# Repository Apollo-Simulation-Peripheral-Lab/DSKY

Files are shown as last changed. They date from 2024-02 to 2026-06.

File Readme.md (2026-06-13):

# DSKY Replica
> This project is still a work-in-progress 

This projects aims to create an affordable and easy to manufacture, yet as realistic as possible replica of the DSKY used in the Apollo program to interface with the Apollo Guidance Computer (AGC).

## Quick start

**Do you want a DSKY but can't build one? Buy one [here](https://shop.ortizma.com)**

**Need Help? Join our Discord [here](https://discord.gg/CHZaYj5UNu)**

**Do you just want to have a DSKY display in your web browser?**
  - Make sure you have NodeJS > 18
  - Run start.bat and answer the prompts

**Do you want to build the whole DSKY replica?**
  - Print the .3mf/.stl meshes found in the '3D Models' folder.
    - The recommended display is the **960x544 AMOLED MIPI display**, connected to the Orange Pi via HDMI through an adapter board.
    - A legacy 40-Pin 5" 800x480 LCD variant also exists but is no longer recommended; new builds should use the AMOLED.
  - Order the PCB:
    - The board is designed to be ordered fully assembled from JLCPCB. The fabrication files (gerbers, BOM, pick-and-place positions) are in the ``Boards/Single_board/production`` folder.
  - Calibrate and flash the firmware:
    - Install PlatformIO into VSCode
    - Open this repository's root folder in VSCode — PlatformIO will pick up ``platformio.ini`` at the root
    - Each ATmega328P has a slightly different internal oscillator. You must first determine your chip's optimal OSCCAL value:
      1. Flash the ``bare_calibration`` environment to run the OSCCAL sweep
      2. Use ``firmware/tools/osccal_reader.py`` to read the sweep results and find the best value
      3. Set the ``-DOSC_CAL=0xNN`` flag in ``platformio.ini`` with your value
      4. Flash the ``bare`` environment with your calibrated firmware
  - Set up the Orange Pi:
    - See the [Orange Pi setup guide](Documentation/orangepi-setup.md).
    - Pre-built .img files have been shared around the community, but they are not recommended as they may be out of date.
  - Make sure you have NodeJS > 18
  - Run start.bat on your PC to launch the web display

**Already have a DSKY and want the latest software?**
  - Updates are installed from the DSKY itself: open the menu (press NOUN three times) and go to **SETTINGS → UPDATE**. See [Documentation/updates.md](Documentation/updates.md).

## Repository contents:
* **Documentation**: Useful information to better understand how the different pieces of the puzzle talk to each other. Includes the [Orange Pi setup guide](Documentation/orangepi-setup.md), the [OTA update system](Documentation/updates.md), how to [deploy code to a device over the network](Documentation/deploying-to-a-device.md), and how to [develop on a physical DSKY with hot reload](Documentation/dev-mode.md).
* **2D Models**: SVG files for alarm labels and backlights.
* **3D Models**:
  * **0.4 Nozzle:** All printable meshes (enclosure, display housing, keyboard plate, mounts, etc.) designed for a standard 0.4mm nozzle.
  * **Keys (0.2 Nozzle + AMS).3mf:** Multi-color key models for a 0.2mm nozzle with AMS.
* **Firmware:** PlatformIO project containing the firmware for the bare ATmega328P on the PCB. Includes OSCCAL calibration tooling.
* **Programs:**
  * **next-dsky**: Full-stack Next.js application that serves as the main DSKY UI and backend. Handles serial communication with the PCB, WebSocket connections to AGC simulators, display rendering, and configuration.    * Requirements: NodeJS >18
    * Running: ``npm install`` then ``npm start`` (or use ``start.bat`` from the repo root)
  * **DSKY-Bridge**: Submodule ([nhadrian/DSKY-Bridge](https://github.com/nhadrian/DSKY-Bridge)) — bridge utility for the DSKY.
  * **nassp-cloud**: Node.js service that monitors NASSP (orbiter simulator) telemetry via WebSocket and manages automatic restarts.
  * **click-generator**: Python program that procedurally generates relay clicking audio sequences to emulate the DSKY's relay boxes.
* **Boards**
  * **Single_board**: Unified KiCad PCB project containing the keyboard matrix, alarm lights, serial interface, and backlight driver. The ``production`` folder contains ready-to-order JLCPCB fabrication files.

## License

This project is licensed under [Creative Commons Attribution-NonCommercial-ShareAlike 4.0 International (CC BY-NC-SA 4.0)](LICENSE).

You are free to build one for yourself, modify the design, and share your changes — as long as you **credit the original**, **do not use it commercially**, and **release your derivatives under the same license**. Commercial sale of this device or its derivatives is not permitted without prior written consent from the copyright holder.

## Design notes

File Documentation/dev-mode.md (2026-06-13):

# Developing on a physical DSKY (dev mode)

This guide is for iterating on the `next-dsky` software **on a real DSKY** with a
fast edit → see-it loop: edits hot-reload on the device in seconds, with no
build and no reboot. It complements:

- [deploying-to-a-device.md](deploying-to-a-device.md) — pushing a built copy to a device (slow; for a one-off install or OTA bootstrap).
- [updates.md](updates.md) — the production OTA update system.

Use **dev mode** while actively developing. Use the other two for releasing.

> The DSKY's keyboard and indicator lamps are wired to the Orange Pi over serial,
> and the display is a Chromium kiosk on the Pi pointing at `localhost:3000`. So
> the server has to run **on the Pi**. Dev mode just runs it in Next's dev (hot
> reload) mode instead of the production build, and you sync your code to it.

## How it works (the safety model)

Dev mode is a purely **in-memory takeover** — it never changes what the device
boots:

- It does **not** touch `~/dsky-releases/current` (the OTA boot pointer). The
  configured production release stays the boot target.
- It **pauses** the production launcher (`orangepi.sh`) with `SIGSTOP` — rather
  than killing it, which would end the X session and drop the screen to the
  lightdm login prompt — and runs `npm run dev` in its place.
- A **reboot returns to production automatically**: nothing persistent changed.
  Pressing `Ctrl-C` also resumes production (the launcher is sent `SIGCONT`).

So you can power-cycle the device at any point and it boots back to normal.

## One-time setup

From your PC:

```bash
# Passwordless SSH (so syncing doesn't prompt on every save)
ssh-copy-id orangepi@<DSKY-IP>

# File-watch tool for live sync
sudo apt install -y inotify-tools

# Copy the dev launcher to the Pi (dev-sync.sh only syncs next-dsky, not the root)
scp dev.sh orangepi@<DSKY-IP>:~/DSKY/dev.sh
```

Finding `<DSKY-IP>` and SSH basics are covered in [deploying-to-a-device.md](deploying-to-a-device.md#step-2--find-the-dsky-and-connect-via-ssh).

## Entering dev mode

In one terminal, start the dev server on the Pi (keep this terminal open — it
shows the live logs):

```bash
ssh -t orangepi@<DSKY-IP> '~/DSKY/dev.sh'
```

- The **first compile is slow** (~90 s on an Orange Pi Zero 2W — it's RAM-tight
  and leans on swap). The splash stays up meanwhile; let it finish.
- When `:3000` responds, the kiosk reloads and you'll see the app in dev mode.

To **edit live**, in a second terminal on your PC:

```bash
./dev-sync.sh <DSKY-IP>        # rsyncs Programs/next-dsky on every save
```

Now edit in your local repo; changes sync to the Pi and hot-reload on the device.

## Leaving dev mode

Press `Ctrl-C` in the `dev.sh` terminal — production resumes on its own (~15 s) —
or `ssh orangepi@<DSKY-IP> 'sudo reboot'`.

## Things to know

- **No UPDATE in SETTINGS while in dev.** OTA is intentionally disabled in dev
  (it keys off `DSKY_RELEASES_DIR`, which only the production launcher sets), so
  the **UPDATE** menu entry is hidden. Return to production to install OTA updates.
- **Server-side edits cause a brief outage.** Editing a server `.ts` file restarts
  the dev server (`tsx watch`), so `:3000` is down for a few seconds. If Chromium
  reloads in that window it shows **"This site can't be reached"** and won't retry.
  The server is fine — just reload the kiosk (see below). Client `.tsx` edits use
  Next HMR and don't cause this.
- **Reloading the kiosk** (no keyboard on the DSKY) from your PC:
  ```bash
  ssh orangepi@<DSKY-IP> 'export DISPLAY=:0; killall chromium-browser chromium; \
    sleep 1; setsid chromium-browser --start-fullscreen --incognito --noerrdialogs \
    --disable-infobars --disable-session-crashed-bubble --no-default-browser-check \
    --no-first-run "http://localhost:3000/?view=screen" >/dev/null 2>&1 < /dev/null &'
  ```

## Troubleshooting

| Symptom | Cause | Fix |
|---|---|---|
| Screen stuck on a login/password prompt | An older `dev.sh` killed `orangepi.sh`, ending the X session (lightdm greeter) | Update `dev.sh` (it now `SIGSTOP`s instead); `sudo reboot` to recover |
| "This site can't be reached" on the DSKY | `:3000` was briefly down during a server restart | Reload the kiosk (command above); the server recovers on its own |
| No **UPDATE** entry in SETTINGS | You're in dev mode (OTA disabled) | Return to production (`Ctrl-C` / reboot) |
| First load takes ~90 s | Zero 2W compiling in dev under tight RAM | Normal — wait; subsequent HMR edits are fast |
| Every save prompts for a password | SSH key not installed | `ssh-copy-id orangepi@<DSKY-IP>` |

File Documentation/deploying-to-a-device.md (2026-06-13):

# Deploying code to a DSKY over the network

This guide explains how to push the `next-dsky` software onto a physical DSKY (the Orange Pi inside it) from your PC, step by step. You need this in two situations:

1. **One-time OTA bootstrap** — installing the over-the-air update system onto a device that doesn't have it yet. After this, the device updates itself from its own menu (see [updates.md](updates.md)) and you never need this guide again for that device.
2. **Developer workflow** — pushing your latest local changes to a test device to try them on real hardware, without cutting a release.

The whole process is done **from your PC's terminal**. You never plug a keyboard into the DSKY. The Orange Pi inside it is a small Linux computer on your network, and you control it remotely over SSH.

> **A note on terminology:** "from your PC" means a terminal on your normal computer. `ssh user@host '<command>'` runs `<command>` *on the Pi*, but you type it from your PC — SSH carries the command across the network for you. You do not need to "log into" the Pi manually for the deploy.

---

## Prerequisites

- The DSKY and your PC are on the **same WiFi/LAN**.
- **NodeJS > 18** on your PC (only needed if you want to test locally first).
- A clone of this repository on your PC with the code you want to deploy:
  ```bash
  git clone https://github.com/Apollo-Replica/DSKY.git
  # or, if you already have it, get the latest:
  cd DSKY && git pull
  ```
  Throughout this guide the clone is referred to as `~/DSKY` — adjust to wherever yours lives.

---

## Step 1 — Get the DSKY onto your WiFi

Skip this if the device is already on your network (e.g. via Ethernet).

### The on-device WiFi portal

In the DSKY menu (press **NOUN** three times) go to **SETTINGS → WIFI**. The device starts a temporary WiFi access point called **"DSKY Replica"** and shows a QR code.

That QR is a *"join this WiFi network"* code, **not** a scan-to-open-a-website code. If this doesn't work, connect it like this:

1. On your phone, open **Settings → WiFi** (the normal network list).
2. Connect to the network named **"DSKY Replica"**.
3. A page opens automatically (like a hotel WiFi portal) where you pick **your home WiFi** and enter its password.
4. The DSKY connects to your WiFi and the "DSKY Replica" network disappears.

---

## Step 2 — Find the DSKY and connect via SSH

### Try the hostname first

The setup guide sets the Pi's hostname to `dsky`, so this may just work:

```bash
ssh orangepi@dsky.local
```

### If that fails: find the IP address

`.local` names rely on mDNS, which **often does not work from WSL** (Linux inside Windows). If you see `Could not resolve hostname dsky.local`, don't fight it — find the device's numeric IP instead:

- **From your router:** open its admin page (usually `http://192.168.1.1`), find the connected-devices / DHCP list, and look for a device named `dsky` or `orangepi`. Note its IP (e.g. `192.168.68.104`).
- **From Windows PowerShell** (not WSL — Windows *can* resolve `.local`):
  ```powershell
  ping dsky.local
  ```
  The reply shows the IP in brackets.

> Your LAN may not use the `192.168.1.x` range. In testing it was `192.168.68.x` — always use whatever your router actually reports.

### Confirm it's the DSKY

Open the IP in your PC's browser with port `3000`:

```
http://<DSKY-IP>:3000
```

If you see the DSKY screen, the IP is correct and the device is reachable. (`Connection timed out` when you try to SSH usually means a **wrong IP**, not a DSKY problem — re-check the IP. `Connection refused` would instead mean SSH isn't running.)

### Connect

```bash
ssh orangepi@<DSKY-IP>
```

- Default password: **`orangepi`** (unless you changed it).
- **The password is invisible as you type** — no dots, no asterisks. This is normal; type it and press Enter.
- A successful login shows a prompt like `orangepi@dsky:~$`. You're now "inside" the Pi. Type `exit` to return to your PC — the deploy below doesn't need you to stay logged in.

---

## Step 3 — Deploy the code

Run these from your PC. Replace `<DSKY-IP>` with the address from Step 2, and `~/DSKY` with your local clone path. You'll be asked for the password (`orangepi`) on each command.

```bash
# 1. Copy the app code to the Pi (skip the big build/dependency folders)
rsync -av --exclude node_modules --exclude .next \
  ~/DSKY/Programs/next-dsky/ orangepi@<DSKY-IP>:~/DSKY/Programs/next-dsky/

# 2. Copy the launcher script
rsync -av ~/DSKY/orangepi.sh orangepi@<DSKY-IP>:~/DSKY/orangepi.sh

# 3. Rebuild on the Pi and reboot
ssh orangepi@<DSKY-IP> 'cd ~/DSKY/Programs/next-dsky && npm install && npm run build && sudo reboot'
```

What to expect:

- **Step 3 is slow** — several minutes. `npm install` and `npm run build` are heavy for the small Orange Pi (the build alone can take ~300s). This is normal; let it finish.
- A successful build prints `✓ Compiled successfully` followed by a small routes table.
- The command ends with **`Connection to <IP> closed by remote host`**. This is **not an error** — it's the `sudo reboot` taking effect and dropping the SSH session, exactly as intended.
- npm warnings about `vulnerabilities` or a `New major version of npm` are harmless noise — ignore them.

> **Why copy from the PC and not `git pull` on the Pi?** Either works, but copying with `rsync` deploys exactly the code on your PC — including local changes you haven't pushed yet — which is what you want for a developer test. For a clean release-based install, `git pull` on the Pi is fine too. The `rsync` excludes (`node_modules`, `.next`) keep the transfer small; Step 3 regenerates them.

---

## Step 4 — Verify

The Pi takes 4-5 minutes to boot back up. Then, on the DSKY:

1. Press **NOUN** three times → **SETTINGS**.
2. A new **UPDATE** entry should appear. (It only shows when over-the-air updates are enabled, which the new `orangepi.sh` does automatically by setting `DSKY_RELEASES_DIR`.)
3. Open **ABOUT** → it now shows a **Version** line.

If you see **UPDATE** in SETTINGS, the deploy succeeded and the device is ready for over-the-air updates from here on.

---

## After this: updates are automatic

Once a device has been bootstrapped with the steps above, you never need to do it again for that device. New versions are published as GitHub releases and installed from the DSKY's own menu (**SETTINGS → UPDATE**), with automatic rollback if anything goes wrong. See [updates.md](updates.md) for how to publish a release and how the safety/rollback mechanism works.

---

## Troubleshooting

| Symptom | Cause | Fix |
|---|---|---|
| `Could not resolve hostname dsky.local` | mDNS not working (common in WSL) | Use the numeric IP — find it via the router or `ping dsky.local` from Windows PowerShell |
| `ssh: connect to host … port 22: Connection timed out` | Wrong IP, or the device isn't reachable at that address | Confirm the IP with `http://<IP>:3000` in a browser; re-check the router's device list |
| `Connection refused` (instead of timeout) | Reachable, but SSH server not running on the Pi | Enable/start `sshd` on the Pi (needs a monitor+keyboard, or a pre-configured image) |
| Password prompt shows nothing as you type | Normal SSH behaviour | Type it blind and press Enter (default: `orangepi`) |
| QR code does nothing when scanned | It's a WiFi-join QR, not a website QR | Connect to the "DSKY Replica" network manually from your phone's WiFi settings |
| "DSKY Replica" network never appears | `wifi-connect` not installed/running on the Pi | Install it (see [orangepi-setup.md](orangepi-setup.md)) or use Ethernet |
| `Connection closed by remote host` at end of Step 3 | The `sudo reboot` dropped the session | Expected — not an error |
| Build seems stuck for a minute or two | The Orange Pi is slow to compile | Wait; ~100s for the build is normal |
| UPDATE doesn't appear in SETTINGS after reboot | `orangepi.sh` not updated, so `DSKY_RELEASES_DIR` isn't set | Make sure Step 3.2 (copying `orangepi.sh`) ran, then reboot |

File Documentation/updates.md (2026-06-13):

# Over-the-air updates

DSKYs update themselves from the device UI — owners never need a terminal. This document explains how the pieces fit together, how to publish an update, and how recovery works.

## For DSKY owners

1. Open the menu (press **NOUN** three times), go to **SETTINGS**.
2. The **UPDATE** entry shows a `NEW vX.Y.Z` badge when an update is available (the device checks automatically every few hours).
3. Select **UPDATE → INSTALL vX.Y.Z**. The display shows download progress, installs, and the DSKY restarts itself. That's it.

If anything goes wrong (power loss, WiFi drop, a bad release), the DSKY keeps or restores the previous version automatically. Updating is always safe.

## How it works

```
GitHub release (vX.Y.Z)                     Orange Pi
┌──────────────────────────┐      ┌─────────────────────────────────┐
│ next-dsky-vX.Y.Z-        │      │ ~/dsky-releases/                │
│   linux-arm64.tar.gz     │ ───▶ │   current  ──▶ vX.Y.Z/          │  ◀─ active (symlink)
│   (prebuilt, + .sha256)  │      │   vX.Y.Z/                       │
└──────────────────────────┘      │   vW.V.U/                       │  ◀─ rollback target
   built by GitHub Actions        │   previous (path of last good)  │
                                  │ ~/DSKY/Programs/next-dsky       │  ◀─ factory install (git clone,
                                  └─────────────────────────────────┘     never touched)
```

- **Releases are prebuilt by CI** ([release.yml](../.github/workflows/release.yml)) on an arm64 runner: `npm ci`, `next build`, dev dependencies pruned, everything tarballed with a SHA-256 checksum. The Orange Pi never runs `npm install` or `next build` — too slow and too fragile on a Zero 2W.
- **The updater lives in the server** ([updater.ts](../Programs/next-dsky/src/server/updater.ts)). It checks `https://api.github.com/repos/<repo>/releases/latest` every 6 hours and on entering the UPDATE screen. Installing means: download → verify checksum → unpack into a *new* directory → carry over device config (`.env`, `ha_entities.json`) → atomically switch the `current` symlink → restart.
- **The launcher is the safety net** ([orangepi.sh](../orangepi.sh)). It always starts the app from `current` (falling back to the factory install if the symlink is missing or broken). A fresh release carries a `.pending-verify` flag; the launcher counts boot attempts while that flag exists, and after 3 failed starts it points `current` back at the previous release. The server removes the flag only after running healthily for 90 seconds.

Failure cases and what happens:

| Failure | Result |
|---|---|
| Network drops mid-download | Install aborts, error shown, current version untouched |
| Corrupted download | Checksum mismatch, install aborts |
| Power loss during install | Symlink not yet switched — old version boots |
| Power loss right after install | New release boots; if broken, crash-loop rollback kicks in |
| New release crash-loops | After 3 attempts the launcher rolls back to the previous release |
| Everything in `~/dsky-releases` is broken | Launcher falls back to the factory git clone |

## Publishing an update (maintainers)

```bash
git tag v0.2.0
git push origin v0.2.0
```

The workflow builds and attaches the package to the release automatically. Devices pick it up on their next periodic check (≤6h) or when the owner opens SETTINGS → UPDATE.

Notes:
- The version shown on devices comes from the tag (CI stamps it into `package.json`); you don't need to bump `package.json` manually.
- Only the **latest** release is offered, so devices that skipped versions jump straight to the newest one. Releases must therefore always be self-contained (no incremental migrations between versions).
- Test on your own DSKY before tagging: the public release goes to every device in the field.

## Environment variables

| Variable | Default | Purpose |
|---|---|---|
| `DSKY_RELEASES_DIR` | `~/dsky-releases` (set by `orangepi.sh`) | Enables OTA and sets the install location. Unset (e.g. desktop installs) = no OTA UI. |
| `DSKY_UPDATE_REPO` | `Apollo-Replica/DSKY` | GitHub repo whose releases are checked. |

## Devices shipped before OTA existed

Older devices don't have the updater yet, so they need one manual deploy over the network to bootstrap it. The full step-by-step (finding the device, SSH, copying the code, rebuilding, and the gotchas around `.local`/WSL) is in **[deploying-to-a-device.md](deploying-to-a-device.md)**. In short:

```bash
ssh orangepi@<DSKY-IP>
cd ~/DSKY && git pull
cd Programs/next-dsky && npm install && npm run build
sudo reboot
```

From then on, all updates are OTA. New SD card images include the updater out of the box.

## Manual recovery

Should a device ever need hands-on recovery (it shouldn't), over SSH:

```bash
rm -f ~/dsky-releases/current   # next boot uses the factory install
sudo reboot
```

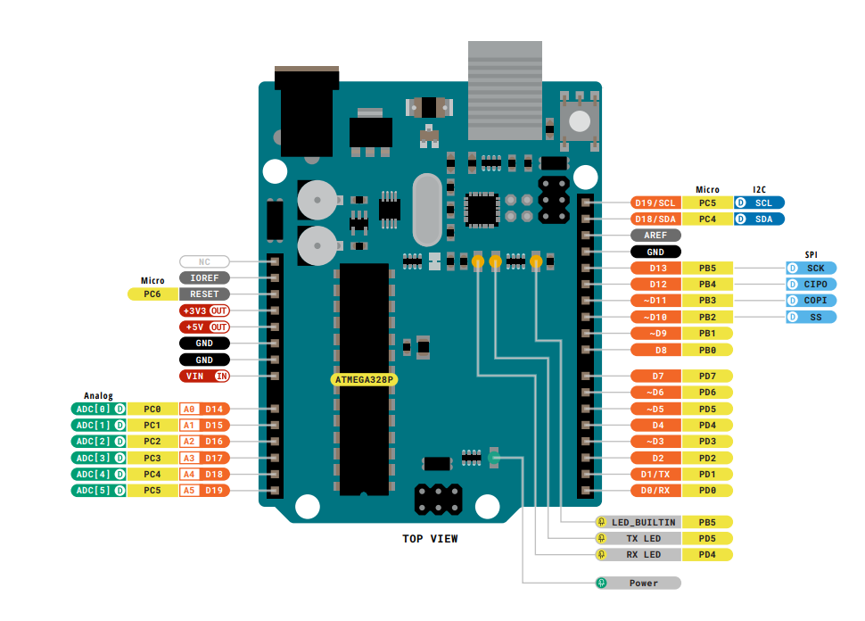
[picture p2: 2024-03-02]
Boards/Main_board/uno.png

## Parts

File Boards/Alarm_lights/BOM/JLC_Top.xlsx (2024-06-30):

Comment | Designator | Footprint | JLCPCB Part #（optional）
White LED | D1,D2,D3,D4,D5 | LED_SMD:LED_1206_3216Metric_Pad1.42x1.75mm_HandSolder | C779809
Orange LED | D6,D7,D8,D9,D10,D11,D12,D13,D14 | LED_SMD:LED_1206_3216Metric_Pad1.42x1.75mm_HandSolder | C3646936
SI2306 | Q1,Q2,Q3,Q4,Q5,Q6,Q7,Q8,Q9,Q10,Q11,Q12,Q13,Q14 | Package_TO_SOT_SMD:SOT-23-3 | C2909908
1k | R1,R2,R3,R4,R5 | Resistor_SMD:R_1206_3216Metric_Pad1.30x1.75mm_HandSolder | C4410
220ohm | R6,R7,R8,R9,R10,R11,R12,R13,R14 | Resistor_SMD:R_1206_3216Metric_Pad1.30x1.75mm_HandSolder | C149887

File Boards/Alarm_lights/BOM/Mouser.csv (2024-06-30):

Source: | C:\Users\evan6\Documents\Projects\Apollo\DSKY\Boards\Alarm_lights\Alarm_lights.kicad_sch
Date: | 3/16/2024 10:12:17 AM
Tool: | Eeschema 7.0.10
Generator: | F:\Electronics\KiCAD\7.0\bin\scripting\plugins/bom_csv_grouped_by_value.py
Component Count: | 51
Collated Components:
Item | Qty | Reference(s) | Value | LibPart | Footprint | Datasheet | DNP | Link | Part Number
1 | 1 | C1 | 1nF | Device:C_Small | Capacitor_SMD:C_1206_3216Metric_Pad1.33x1.80mm_HandSolder | ~ |  | https://www.mouser.com/ProductDetail/80-C1206C102K5RAC | C1206C102K5RAC
2 | 5 | D1, D2, D3, D4, D5 | White LED | Device:LED_Small | LED_SMD:LED_1206_3216Metric_Pad1.42x1.75mm_HandSolder | ~ |  | https://www.mouser.com/ProductDetail/859-LTW-150TK | LTW-150TK
3 | 9 | D6, D7, D8, D9, D10, D11, D12, D13, D14 | Orange LED | Device:LED_Small | LED_SMD:LED_1206_3216Metric_Pad1.42x1.75mm_HandSolder | ~ |  | https://www.mouser.com/ProductDetail/859-LTST-C230KFKT | LTST-C230KFKT
4 | 1 | J1 | PinsLeft | Connector:Conn_01x10_Socket | Connector_PinSocket_2.54mm:PinSocket_1x10_P2.54mm_Vertical | ~
5 | 1 | J2 | PinsBottom | Connector:Conn_01x05_Socket | Connector_PinSocket_2.54mm:PinSocket_1x05_P2.54mm_Vertical | ~
6 | 1 | J3 | PinsRight | Connector:Conn_01x10_Socket | Connector_PinSocket_2.54mm:PinSocket_1x10_P2.54mm_Vertical | ~
7 | 1 | J4 | JST | Connector:Conn_01x05_Socket | Connector_JST:JST_XH_B5B-XH-A_1x05_P2.50mm_Vertical | ~
8 | 15 | Q1, Q2, Q3, Q4, Q5, Q6, Q7, Q8, Q9, Q10, Q11, Q12, Q13, Q14, Q15 | SI2306 | Device:Q_NMOS_GSD | Package_TO_SOT_SMD:SOT-23-3 | ~ |  | https://www.mouser.com/ProductDetail/833-SI2306-TP | SI2306-TP
9 | 7 | R1, R2, R3, R4, R5, R16, R17 | 1k | Device:R_Small | Resistor_SMD:R_1206_3216Metric_Pad1.30x1.75mm_HandSolder | ~ |  | https://www.mouser.com/ProductDetail/652-CR1206FX-1001ELF | CR1206-FX-1001ELF
10 | 9 | R6, R7, R8, R9, R10, R11, R12, R13, R14 | 220 | Device:R_Small | Resistor_SMD:R_1206_3216Metric_Pad1.30x1.75mm_HandSolder | ~ |  | https://www.mouser.com/ProductDetail/652-CR1206FX-2200ELF | CR1206-FX-2200ELF
11 | 1 | R15 | 10k | Device:R_Small | Resistor_SMD:R_1206_3216Metric_Pad1.30x1.75mm_HandSolder | ~ |  | https://www.mouser.com/ProductDetail/652-CR1206FX-1002ELF | CR1206-FX-1002ELF

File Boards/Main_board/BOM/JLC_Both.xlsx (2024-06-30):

Comment | Designator | Footprint | JLCPCB Part #（optional）
1k | R7,R9,R10,R11,R12,R13,R14,R15,R16,R17,R18,R19,R20,R21,R22,R23,R24,R25,R26,R27 | Resistor_SMD:R_1206_3216Metric_Pad1.30x1.75mm_HandSolder | C4410
10k | R1,R2,R3,R4,R5,R6 | Resistor_SMD:R_1206_3216Metric_Pad1.30x1.75mm_HandSolder | C17902
1nF | C1 | Capacitor_SMD:C_1206_3216Metric_Pad1.33x1.80mm_HandSolder | C9196
SI2306 | Q2 | Package_TO_SOT_SMD:SOT-23-3 | C2909908
MX Blue | SW1,SW2,SW3,SW4,SW5,SW6,SW7,SW8,SW9,SW10,SW11,SW12,SW13,SW14,SW15,SW16,SW17,SW18,SW19 | MX1A-E1NW | C5120587
3mm White LED | D1,D2,D3,D4,D5,D6,D7,D8,D9,D10,D11,D12,D13,D14,D15,D16,D17,D18,D19 | White LED D=3 | C282138
5P XH JST | J1 | 5P XH JST | C157991

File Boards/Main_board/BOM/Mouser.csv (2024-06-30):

Source: | C:\Users\evan6\Documents\Projects\Apollo\DSKY\Boards\Main_board\Main_board.kicad_sch
Date: | 3/24/2024 1:51:13 PM
Tool: | Eeschema 7.0.10
Generator: | F:\Electronics\KiCAD\7.0\bin\scripting\plugins/bom_csv_grouped_by_value.py
Component Count: | 28
Collated Components:
Item | Qty | Reference(s) | Value | LibPart | Footprint | Datasheet | DNP | Link | Part Number
1 | 1 | A1 | Arduino_Nano_Socket | PCM_arduino-library:Arduino_Nano_Socket | PCM_arduino-library:Arduino_Nano_Socket | https://docs.arduino.cc/hardware/nano
2 | 1 | J1 | Conn_01x05_Socket | Connector:Conn_01x05_Socket | Connector_JST:JST_XH_B5B-XH-A_1x05_P2.50mm_Vertical | ~
3 | 2 | J2, J3 | Conn_01x04_Socket | Connector:Conn_01x04_Socket | Connector_JST:JST_XH_B4B-XH-A_1x04_P2.50mm_Vertical | ~
4 | 5 | R1, R2, R3, R4, R5 | 10k | Device:R_Small | Resistor_SMD:R_1206_3216Metric | ~ |  | https://www.mouser.com/ProductDetail/652-CR1206FX-1002ELF | CR1206-FX-1002ELF
5 | 1 | SW1 | VERB | Switch:SW_Push | Button_Switch_Keyboard:SW_Cherry_MX_1.00u_Plate | ~
6 | 1 | SW2 | NOUN | Switch:SW_Push | Button_Switch_Keyboard:SW_Cherry_MX_1.00u_Plate | ~
7 | 1 | SW3 | + | Switch:SW_Push | Button_Switch_Keyboard:SW_Cherry_MX_1.00u_Plate | ~
8 | 1 | SW4 | - | Switch:SW_Push | Button_Switch_Keyboard:SW_Cherry_MX_1.00u_Plate | ~
9 | 1 | SW5 | 0 | Switch:SW_Push | Button_Switch_Keyboard:SW_Cherry_MX_1.00u_Plate | ~
10 | 1 | SW6 | 7 | Switch:SW_Push | Button_Switch_Keyboard:SW_Cherry_MX_1.00u_Plate | ~
11 | 1 | SW7 | 4 | Switch:SW_Push | Button_Switch_Keyboard:SW_Cherry_MX_1.00u_Plate | ~
12 | 1 | SW8 | 1 | Switch:SW_Push | Button_Switch_Keyboard:SW_Cherry_MX_1.00u_Plate | ~
13 | 1 | SW9 | 8 | Switch:SW_Push | Button_Switch_Keyboard:SW_Cherry_MX_1.00u_Plate | ~
14 | 1 | SW10 | 5 | Switch:SW_Push | Button_Switch_Keyboard:SW_Cherry_MX_1.00u_Plate | ~
15 | 1 | SW11 | 2 | Switch:SW_Push | Button_Switch_Keyboard:SW_Cherry_MX_1.00u_Plate | ~
16 | 1 | SW12 | 9 | Switch:SW_Push | Button_Switch_Keyboard:SW_Cherry_MX_1.00u_Plate | ~
17 | 1 | SW13 | 6 | Switch:SW_Push | Button_Switch_Keyboard:SW_Cherry_MX_1.00u_Plate | ~
18 | 1 | SW14 | 3 | Switch:SW_Push | Button_Switch_Keyboard:SW_Cherry_MX_1.00u_Plate | ~
19 | 1 | SW15 | CLR | Switch:SW_Push | Button_Switch_Keyboard:SW_Cherry_MX_1.00u_Plate | ~
20 | 1 | SW16 | PRO | Switch:SW_Push | Button_Switch_Keyboard:SW_Cherry_MX_1.00u_Plate | ~
21 | 1 | SW17 | KEYREL | Switch:SW_Push | Button_Switch_Keyboard:SW_Cherry_MX_1.00u_Plate | ~
22 | 1 | SW18 | ENTR | Switch:SW_Push | Button_Switch_Keyboard:SW_Cherry_MX_1.00u_Plate | ~
23 | 1 | SW19 | RSET | Switch:SW_Push | Button_Switch_Keyboard:SW_Cherry_MX_1.00u_Plate | ~

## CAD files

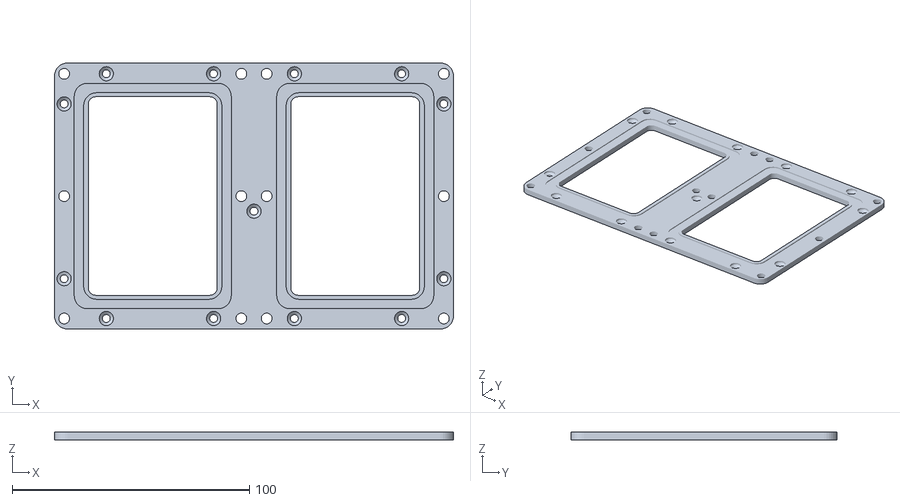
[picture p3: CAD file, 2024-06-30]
3D Models/Common Models/Gasket Top.stl
168.1 x 112.1 x 3.18

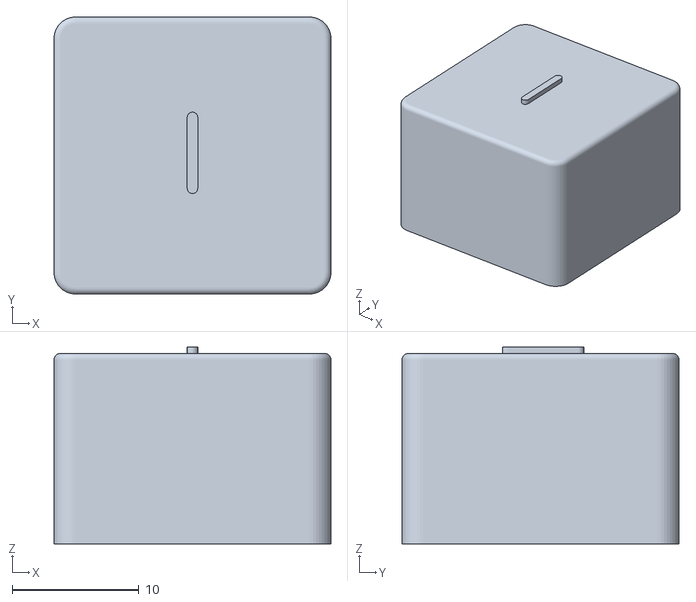
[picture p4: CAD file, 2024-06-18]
3D Models/Common Models/Keys/1.stl
21.8 x 21.8 x 15.5

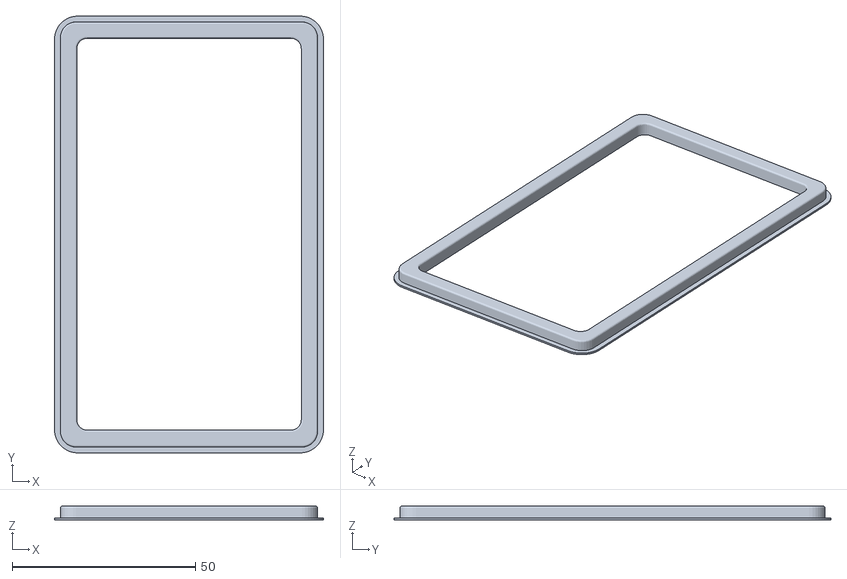
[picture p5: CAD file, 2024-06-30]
3D Models/HDMI Version/Frame (HDMI).stl
73.4 x 119.3 x 3.76

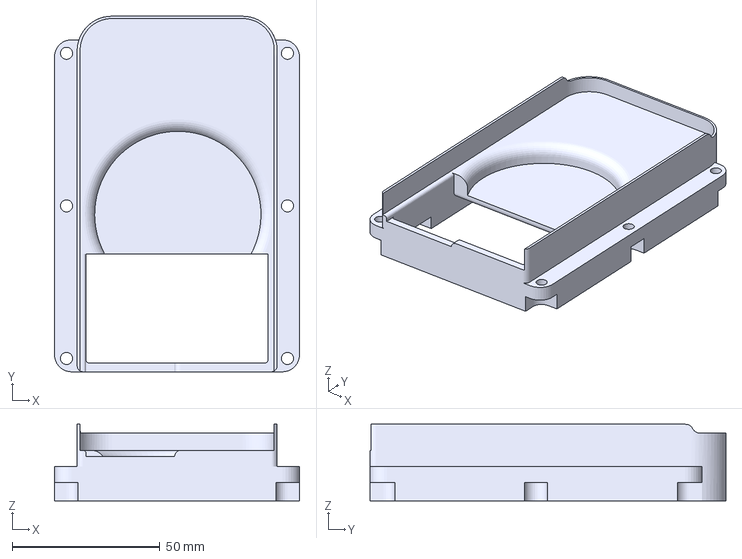
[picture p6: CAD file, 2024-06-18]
3D Models/iPhone 12 Mini Version/Display Housing (iPhone 12 Mini).3mf
82.8 x 120.2 x 25.9 mm

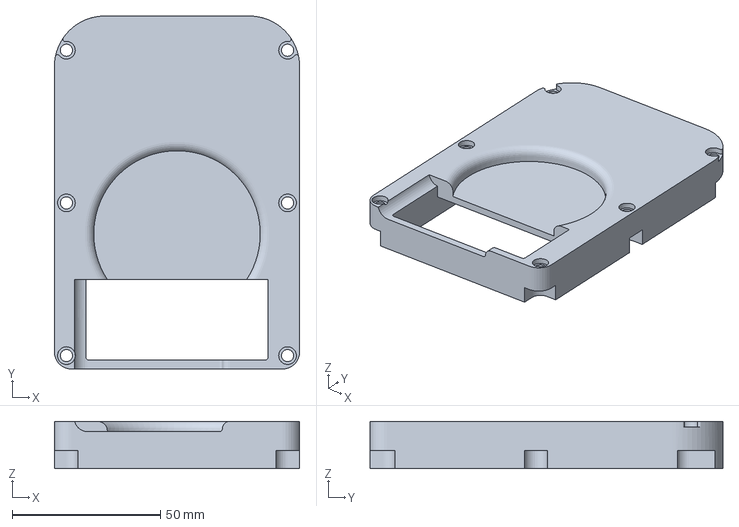
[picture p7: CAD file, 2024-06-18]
3D Models/iPhone 13 Version/Display Housing (iPhone 13).3mf
82.8 x 119.2 x 16.0 mm

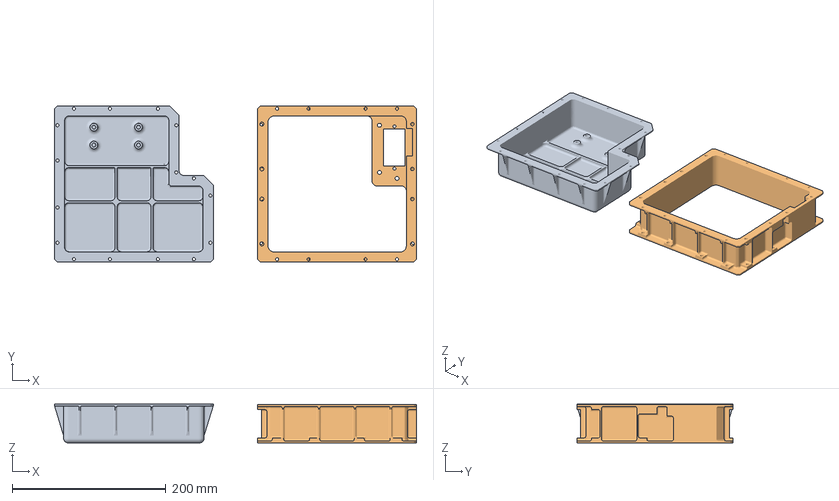
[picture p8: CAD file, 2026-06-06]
3D Models/Replica Enclosure.3mf
470.3 x 203.2 x 50.4 mm
Enclosure bottom
Enclosure middle

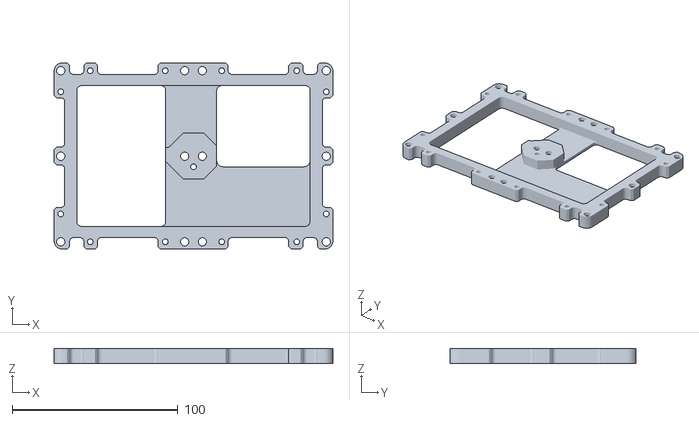
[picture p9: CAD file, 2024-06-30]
3D Models/Common Models/Gasket Bottom.stl
168.1 x 112.3 x 9.30

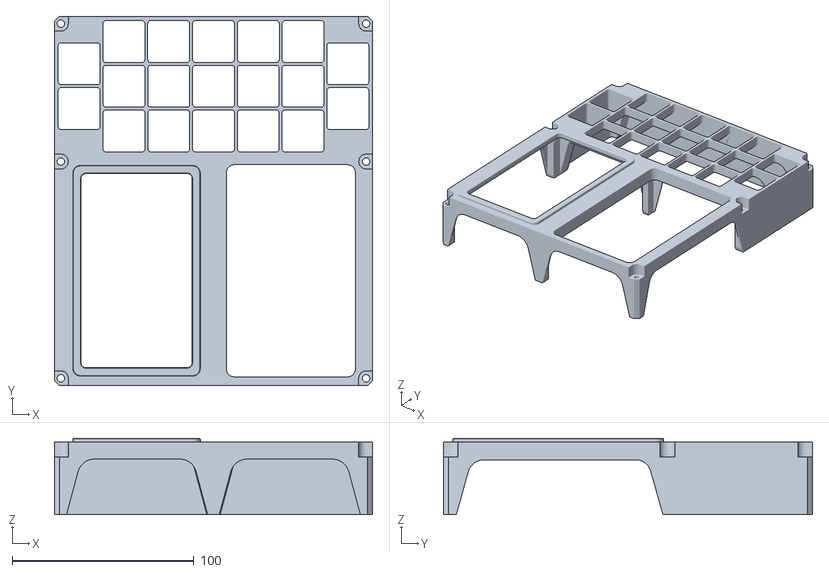
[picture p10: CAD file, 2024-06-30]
3D Models/HDMI Version/Cover+Frame (HDMI).stl
175.3 x 203.2 x 42.0

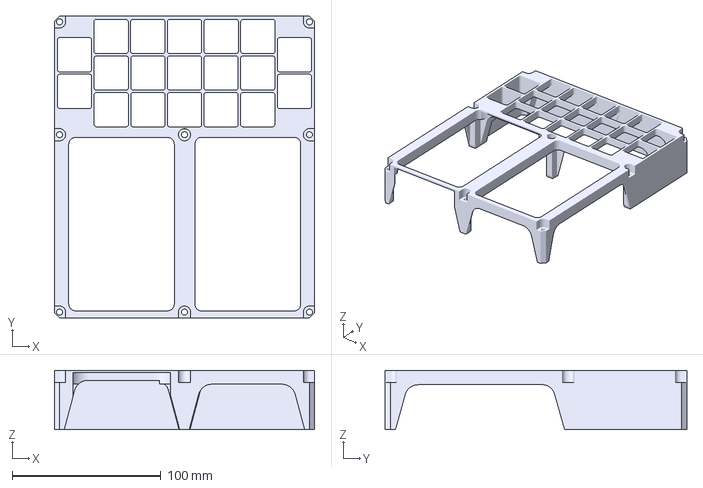
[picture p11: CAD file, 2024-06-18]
3D Models/iPhone 12 Mini Version/Cover (iPhone 12 Mini).3mf
175.3 x 203.2 x 39.9 mm

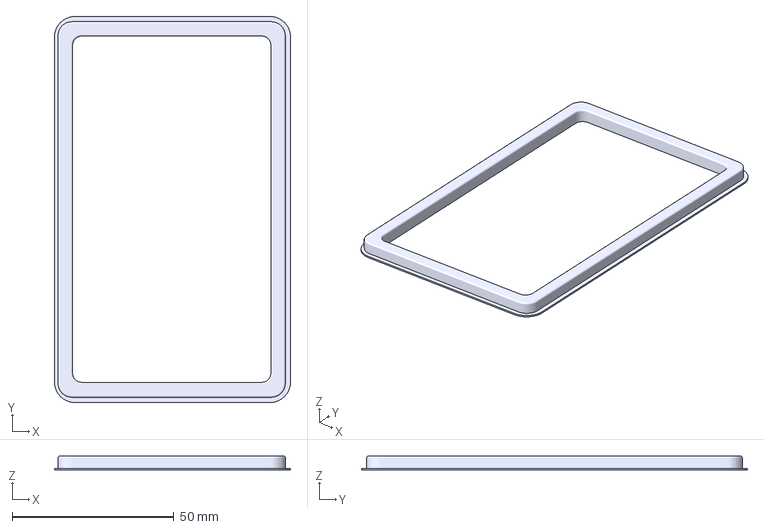
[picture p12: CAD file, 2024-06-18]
3D Models/iPhone 13 Version/Frame (iPhone 13).3mf
72.9 x 119.3 x 4.26 mm

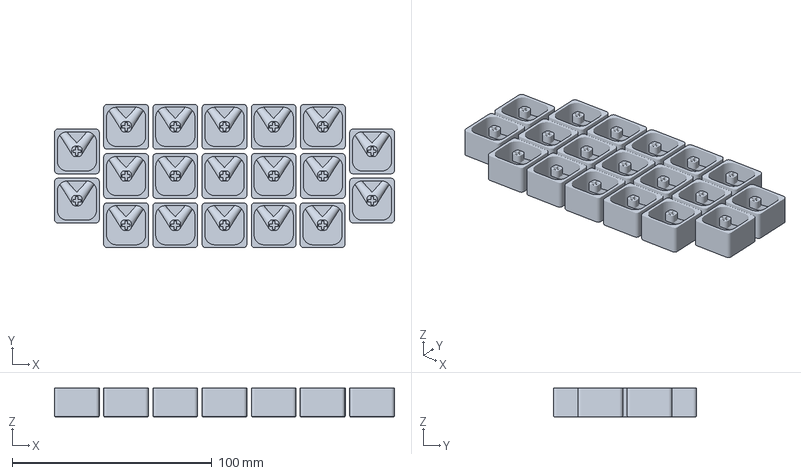
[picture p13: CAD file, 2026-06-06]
3D Models/Keys (0.2 Nozzle + AMS).3mf
170.3 x 71.7 x 14.4 mm

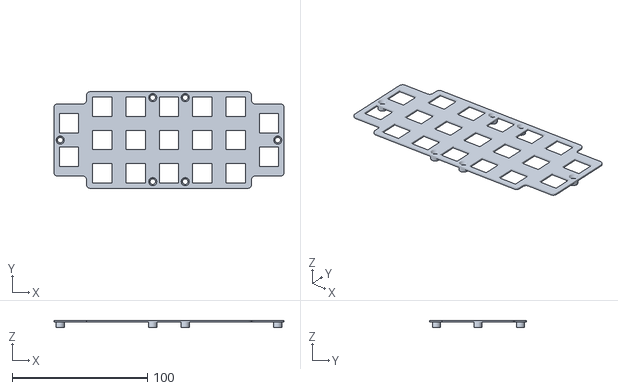
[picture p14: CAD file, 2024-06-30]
3D Models/Common Models/Keyboard Plate.stl
170.0 x 71.4 x 5.30

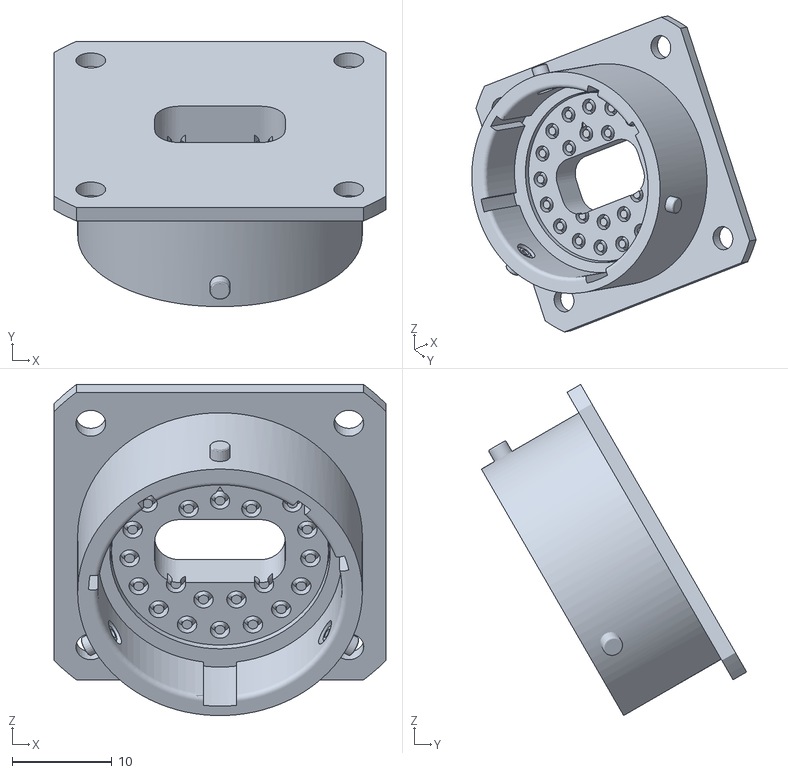
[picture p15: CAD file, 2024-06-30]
3D Models/HDMI Version/Connector.stl
33.3 x 26.6 x 33.2

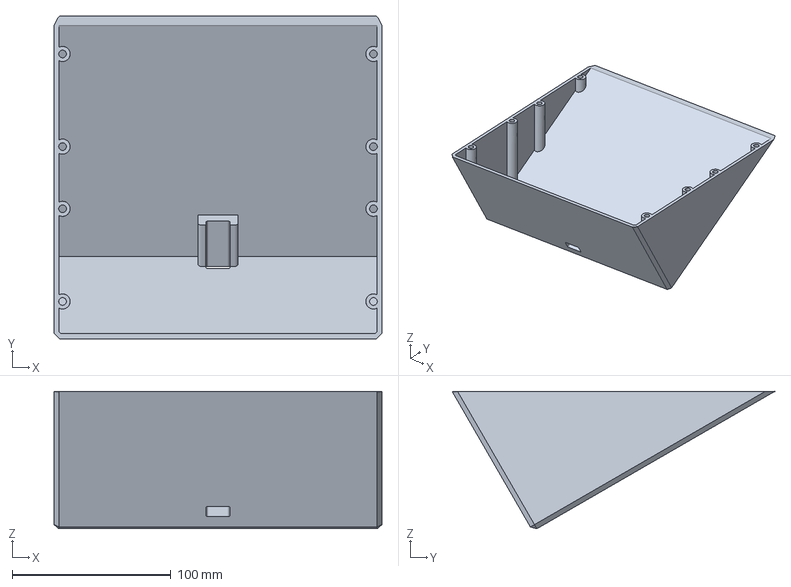
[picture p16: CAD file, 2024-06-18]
3D Models/iPhone 12 Mini Version/Compact Mount (iPhone 12 Mini).3mf
206.3 x 203.2 x 86.5 mm

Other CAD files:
3D Models/Common Models/Keys/5.stl
3D Models/Common Models/Keys/6.stl
3D Models/iPhone 13 Version/Cover (iPhone 13).3mf
3D Models/Common Models/Alarm Housing Top.stl
3D Models/(OLD) Display Housing (LCD).3mf
3D Models/Common Models/Alarm Holder 3x7mm.3mf
3D Models/Common Models/Alarm Holder 3x9mm.3mf
3D Models/Common Models/Alarm Housing Bottom.stl
3D Models/Common Models/Alarm Splitter.3mf
3D Models/Common Models/Enclosure middle (bottom half).3mf
3D Models/Common Models/Enclosure middle (single print discouraged).3mf
3D Models/Common Models/Enclosure middle (top half).3mf
3D Models/Common Models/Keyboard Holder.stl
3D Models/Common Models/Keys/+.stl
3D Models/Common Models/Keys/-.stl
3D Models/Common Models/Keys/0.stl
3D Models/Common Models/Keys/2.stl
3D Models/Common Models/Keys/3.stl
3D Models/Common Models/Keys/4.stl
3D Models/Common Models/Keys/7.stl
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

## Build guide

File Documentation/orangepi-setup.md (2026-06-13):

# Orange Pi Zero 2W Setup Guide

This guide walks you through setting up an Orange Pi Zero 2W from scratch to run the DSKY software. This is the recommended approach over using pre-built .img files, which may be out of date.

## Base OS

Flash the official **Orange Pi Zero 2W** image (Ubuntu Jammy, arm64) to your SD card using your preferred tool (e.g. balenaEtcher, dd).

Default credentials are typically `orangepi` / `orangepi`.

## Initial setup

After first boot, connect via SSH or a monitor and keyboard.

```bash
# Set hostname
sudo hostnamectl set-hostname dsky

# Update the system
sudo apt update && sudo apt upgrade -y
```

### Create a swap file

The Orange Pi Zero 2W has limited RAM. A swap file helps prevent out-of-memory issues during `npm install` and builds.

```bash
sudo fallocate -l 1G /swapfile
sudo chmod 600 /swapfile
sudo mkswap /swapfile
sudo swapon /swapfile

# Make it permanent
echo '/swapfile swap swap sw 0 0' | sudo tee -a /etc/fstab
```

## Install dependencies

```bash
sudo apt install -y git x11vnc
```

### VirtualAGC (optional)

If you want to run the AGC simulator locally on the Orange Pi:

```bash
sudo apt-get install -y wx2.8-headers libwxgtk2.8-0 libsdl1.2debian libncurses5
```

Build VirtualAGC from source or use a pre-built release. The binaries should end up in `~/VirtualAGC/bin/` (notably `yaAGC`).

## Clone the DSKY repository

```bash
cd ~
git clone https://github.com/Apollo-Replica/DSKY.git
cd DSKY/Programs/next-dsky
npm install
npm run build
```

## Configure appliance-mode boot

Appliance mode boots the Orange Pi straight to the DSKY UI — no desktop, no login prompt, no visible Linux. A helper script does all the setup:

```bash
cd ~/DSKY
bash Programs/orangepi-utilities/setup-appliance-mode.sh
sudo reboot
```

What the script does:

- Installs `openbox`, `feh`, and `unclutter` (minimal WM, splash loader, cursor hider).
- Disables `apt-daily.timer` / `apt-daily-upgrade.timer` and removes `update-manager`/`update-notifier` so auto-updates don't fight the appliance.
- Sets silent kernel boot args in `/boot/orangepiEnv.txt` (`quiet splash loglevel=0`, hides console cursor and blanking).
- Registers a custom `dsky` X session and configures LightDM to auto-login the `orangepi` user into it.
- Creates `~/.xsession`, which launches `openbox` and runs `~/DSKY/orangepi.sh`.
- Silences the `getty@tty1` login banner.
- Swaps the Plymouth boot watermark to the DSKY mission patch.

After reboot: power on → splash image (or black screen) → DSKY UI.

The splash image lives at `~/DSKY/Programs/orangepi-utilities/splash.png`. Use portrait orientation matching your display (e.g. 544×960). If the file is missing the screen stays black until the UI is ready.

## Display rotation

The DSKY display is mounted in portrait orientation, so the HDMI output needs to be rotated 90° counterclockwise. `orangepi.sh` applies an xrandr transform automatically at startup.

The default transform is `0,-1,544,1,0,0,0,0,1`, where `544` is the height of the recommended 960×544 AMOLED display. Override via environment variables in `~/.xsession` (created by the appliance-mode script) only if your display differs:

```bash
#!/bin/bash
export DSKY_XRANDR_OUTPUT=HDMI-1                    # default: HDMI-1
export DSKY_XRANDR_TRANSFORM=0,-1,544,1,0,0,0,0,1   # match your display height
export DSKY_DISPLAY=amoled544                       # or lcd480 for the legacy 800×480 panel
openbox &
~/DSKY/orangepi.sh
```

> For the legacy 800×480 LCD: use `480` in place of `544` in the transform and set `DSKY_DISPLAY=lcd480`. Exporting `DSKY_DISPLAY` in `~/.xsession` is preferred over editing `Programs/next-dsky/.env` — `.xsession` env vars propagate through `orangepi.sh` into `next-dsky` at runtime.

## VNC access (optional)

To remotely view and control the Orange Pi's display:

```bash
# Set a VNC password
x11vnc -storepasswd

# Create a systemd service (more reliable than autostart desktop entries)
sudo tee /etc/systemd/system/x11vnc.service << 'EOF'
[Unit]
Description=x11vnc VNC server
After=display-manager.service

[Service]
Type=simple
ExecStart=/usr/bin/x11vnc -forever -usepw -display :0 -auth guess
User=orangepi
Restart=on-failure
RestartSec=3

[Install]
WantedBy=graphical.target
EOF

sudo systemctl daemon-reload
sudo systemctl enable x11vnc
sudo systemctl start x11vnc
```

## WiFi Connect (optional)

[wifi-connect](https://github.com/balena-os/wifi-connect) provides a captive portal for configuring WiFi on a headless device. The DSKY's configuration UI can trigger it.

```bash
# Install build dependencies
sudo apt install -y build-essential pkg-config libnm-dev libdbus-1-dev network-manager curl

# Install Rust
curl https://sh.rustup.rs -sSf | sh
source "$HOME/.cargo/env"

# Clone and build
git clone https://github.com/balena-os/wifi-connect.git ~/wifi-connect
cd ~/wifi-connect
cargo build --release

# Install the binary
sudo cp target/release/wifi-connect /usr/local/sbin/wifi-connect
```

The `orangepi.sh` launcher script already passes `--wifi-connect` to `next-dsky` when needed.

## Software updates

After this initial setup the device updates itself over the air: new versions published as GitHub releases can be installed from the DSKY's own menu (**SETTINGS → UPDATE**), with automatic rollback if anything goes wrong. The git clone made above acts as the permanent factory fallback — don't delete it. See [updates.md](updates.md) for details.

## Notes

- The Orange Pi connects to the PCB via USB serial (`/dev/ttyUSB0`).
- The `orangepi.sh` script handles display rotation, splash, starting `next-dsky` with the correct serial port, opening Chromium fullscreen, and restarting on crash.
- `unclutter` is launched by `orangepi.sh` to hide the mouse cursor immediately.
- The fstab uses `noatime,commit=600` to reduce SD card writes.
- To revert appliance mode: remove `~/.xsession`, `/etc/lightdm/lightdm.conf.d/50-appliance.conf`, `/usr/share/xsessions/dsky.desktop`, and `/etc/systemd/system/getty@tty1.service.d/override.conf`, then reboot.

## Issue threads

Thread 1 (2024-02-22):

Analysis of LED Luminosity

Aeasala, 2024-02-22:
The characteristics and behavior of the orange/white LEDs should be observed, tuning the current-limiting resistance as needed if changes are found necessary.

It has been noted that the white LED has a ~3V Vf drop, and the orange LED a ~2V Vf drop.  Planned forward current is 20mA, to be achieved with a 5V supply.

Pablo-Ortiz-Lopez, 2024-02-22:
With initial experimentation, it has been determined that white LEDs require considerably less current to achieve a similar luminosity than an orange led with a higher forward current.

With this in mind, and the fact that maximum led luminosity is probably something we want to let the final user to decide, I propose making a table where, given a set of possible orange led resistor values, we derive:

- Orange LED forward current
- White LED resistor value
- White LED forward current

With the constraint that both sets of leds shall have similar maximum luminosities.

Aeasala, 2024-03-07:
220o for Orange
1ko for White

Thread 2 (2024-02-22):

Create Bill of Materials

Aeasala, 2024-02-22:
Shall be tracked on the following spreadsheet: https://docs.google.com/spreadsheets/d/1E8URkYszez7U4Jcu4ujoRunJUbHAx5XhUrIbJif9rSM/edit?usp=sharing

Unsure how revisions on this repo should be handled in the context of version control for this doc.

KiCAD should be capable of automatically creating a .csv-formatted BOM -- components just need to have their desired parameters specified in the schematic, e.g. P/N, MFR., price, qty., package type/size...

Closed 2024-03-08.

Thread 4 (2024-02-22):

Display Discussion

Aeasala, 2024-02-22:
Measurements of current draw from the display are to be taken (at different brightness levels, preferably).

If brightness is to be limited, solutions can be discussed here.  (resistive divider setup on potentiometer or clamping diode?)

https://www.amazon.com/gp/product/B0CKRJ81B5/ref=ox_sc_saved_title_2?smid=A1PKC2PUMNR8VD&th=1

Aeasala, 2024-02-22:
http://www.lcdwiki.com/4.0inch_SPI_Module_ILI9486

power consumption stated as "TBD", haha.

Closed 2024-03-21.

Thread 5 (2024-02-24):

Alarm Lights PCB Work

Aeasala, 2024-02-24:
for alarm board

Pablo-Ortiz-Lopez, 2024-02-25:
While the current state of the PR would satisfy the minimum requirement of a functional alarm board, I believe improvement is possible on the following two issues:

- The JST header should be parallel to one of the main board's I2C headers, and the pins lined up so that a straight path between them is achieved, and minimal twisting of the connector is needed to join both boards
- There should be a separate power rail, specifically to feed the LED's, so that the board can be driven with an independent power rail from the one used for the uno's 5V logic. This would allow for PWM and higher voltages to be applied on the LED's.

Closed 2024-03-01.

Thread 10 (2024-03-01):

Prototyping Results: Alarm PCB

Aeasala, 2024-03-01:
Needed:

- Verification of 0%, 100% duty cycle appearance.
- Confirm that LED brightness is not affected by total qty. of LEDs powered.  Otherwise, determine maximum duty cycle.
- Confirm that powered LEDs do not "bleed" into other unpowered LEDs (noted in https://github.com/Pablo-Ortiz-Lopez/DSKY/issues/9)
- Measure total current draw at various states.
- Measure supply droop during i2c transactions and active PWM, whether addition of bulk decoupling is necessary.

Aeasala, 2024-03-05:
GS resistors of lamp FETs "bleed" into each other.  If one lamp is on, its gate-source resistance is 1000ohms, and source-to-ground resistance is (1000/13) **_77 ohms_**.  This is an unfortunate case of pin outputs not being HI-Z when low.

Remedies:
1. PMOS high-side switching
2. If configurable, go to HI-Z output when LOW
3. Reference pulldowns to GND, rather than PWMCom
4. Omit pulldowns if found unnecessary with IO expander.  (i.e. already includes weak pulldowns to GND)

Aeasala, 2024-03-05:
Given the PCF IC claims "strong pull-downs" with "weak pull-ups", the best option moving forward is to go for a pull-up option.  This will prevent the "bleeding" issue altogether, and allow proper driving provided the stated weakness.

Aeasala, 2024-03-07:
Pulldowns to be omitted completely on IO FETs

470o/2.2nF gate filter to be implemented on PWM FET due to observed capacitive coupling.  Causes white LEDs to slightly turn on when only orange LEDs are active, presumably due to their different characteristics (voltage drop).  Theory is that Cds is at play as PWMCom switches, permitting a quick pulse of current from the White LEDs.

1us Trf is sufficient for minimum duty cycle, even at 980Hz.  Typ. is ~60nsTrf.

Aeasala, 2024-03-21:
Early prototyping findings have been completed, and the board is at an acceptable design state.  Any remaining findings, suggestions, modifications, or improvements shall be addressed in https://github.com/Apollo-Simulation-Peripheral-Lab/DSKY/issues/30

Closed 2024-03-21.

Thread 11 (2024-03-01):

Prototyping Results: Keyboard PCB

Aeasala, 2024-03-01:
Needed:

- Verification of button matrix functionality.
- Measurement of current draw, supply droop while connected to Alarm PCB.
- Verification of solderability & alignment for buttons, as this is performed by-hand.

Closed 2024-07-01.

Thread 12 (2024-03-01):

Microcontroller Change

Aeasala, 2024-03-01:
https://es.aliexpress.com/item/1005006053215107.html

Pablo-Ortiz-Lopez, 2024-03-01:
After some analysis, the initial microcontroller board chosen (Arduino UNO), is deemed to be too big to fit in the area below the keys, where it's supposed to be placed. It is because of this that I propose switching to an Arduino Micro board.

The Arduino Micro is essentially a shrunk down Arduino UNO, without sacrificing any functionality that is needed for this project.
If there is no objection I shall update the branch #8 to use this board instead.

Aeasala, 2024-03-02:
New uC implemented as of https://github.com/Pablo-Ortiz-Lopez/DSKY/pull/8 & https://github.com/Pablo-Ortiz-Lopez/DSKY/issues/7

Aeasala, 2024-03-02:
New uC implemented as of PR https://github.com/Pablo-Ortiz-Lopez/DSKY/pull/8 & Issue https://github.com/Pablo-Ortiz-Lopez/DSKY/issues/7

Closed 2024-03-02.

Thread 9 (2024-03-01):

Confirm Alarm Board Pulldown Values

Aeasala, 2024-03-01:
In the case that the I/O expander pins can sink current when off (not Hi-Z), we may need to increase the pulldowns from 1k to 47k/100k/220k, etc.  May not be able to reach true 0% duty cycle on PWM, otherwise.

Early in the morning for me, so may be over-thinking.

Closed 2024-03-08.

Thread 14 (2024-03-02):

Software PWM Control

Aeasala, 2024-03-02:
PWM value should be received from the application level as a `{uint8_t} brightnessVal` from [0, 255]

Alarm board PWM value should be [0, 255] from dim to bright.

Future high-side p-channel FET should be `{255 - brightnessVal}`, or ones-complement `{~brightnessVal}`, i.e. from [255, 0] for dim to bright.

Aeasala, 2024-03-04:
i will try to get some info today when the boards arrive

Aeasala, 2024-07-01:
has been completed by #22

Closed 2024-07-01.

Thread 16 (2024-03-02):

Implement Display Driver

Aeasala, 2024-03-02:

Aeasala, 2024-03-21:
The TFT Display Driver has been tabled.  See: https://github.com/Apollo-Simulation-Peripheral-Lab/DSKY/issues/34

Closed 2024-03-21.

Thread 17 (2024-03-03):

Implement Web emulator of display

Pablo-Ortiz-Lopez, 2024-03-03:
To be used by any phone to render the DSKY display state. It must interact with the "api-dsky" software, which will send the state updates.

Pablo-Ortiz-Lopez, 2024-03-06:
The renderer has been implemented and only needs minor fixes currently

Closed 2024-03-06.

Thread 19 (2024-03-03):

Design 3D Models to fit the PCB's into the design

Pablo-Ortiz-Lopez, 2024-03-03:
Both the Alarms and Keyboard PCB require a holder model, and a top plate. In the case of the alarms pcb, the top plate will make sure no light bleeds to adjacent cells. In the case of the keyboard PCB, the top plate will serve the purpose of securely holding the cherry switches in place.

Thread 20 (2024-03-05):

Consistency issues with few LEDs and low duty cycle

Aeasala, 2024-03-05:
The apparent brightness of the LEDs is significantly greater at low duty cycles, and few powered.  (1-2 LEDs)

Ruled out:
- Switching Frequency
- Drive capability

This may be due to drain-source capacitance on the PWM FET, not having enough time to completely charge with only 1 LED active during the OFF state. (LED FET is still turned on while capacitance charges.)

Aeasala, 2024-03-05:
As other pins have a shared pulldown, this is due to the lack of a hi-z output state.  LOW pins begin to sink current from HIGH pins, causing a stronger drive.  Hard to explain, but some isolation will be needed.

Aeasala, 2024-03-05:
Pulldowns may/may not become DNP depending on I/O expander behavior.

Aeasala, 2024-03-07:
PU PD omitted.

Closed 2024-03-07.

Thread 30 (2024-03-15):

Alarm Board Development - Closeout Tasks

Aeasala, 2024-03-15:
- It would be useful to include a PCF8575 footprint beneath the IO expander.  This would allow users to choose between installing a standalone chip, or an off-the-shelf plug-in assembly.
- Determine if decoupling caps are necessary.  Preliminary results from prototyping are dictating that they are not.
- Change 470o/2.2nF filter to 1k/1nF.  This removes one unique component from the bill-of-materials, replacing it with an already used 1kohm resistor.  Nearly the same time constant.
- Attach or include mouser/digikey link to purchase entire set of board components.  This would be a great convenience.
- Perform once-over check of component parameters, to ensure that their definitions and fields are consistent amongst others.
- Create a local library for custom footprints -- one which is tracked in version control.
- Tie silkscreen print of version, board name to values in the lower-right corner of the schematic.  Minimizes possibility of being forgotten between revisions.

Finally, signature should also be edited, 1.5mmx1.5mm size, bold & italic, in the format of:
**_ASPlab
[DSKY] Alarm Board
Rev. x.y.z_**

Aeasala, 2024-03-16:
To research for future modification:

- 3 (or 2) LEDs/lamp, distributing same (or more) current between them per lamp.

Aeasala, 2024-03-18:
in its current state, the PCF8575 footprint addition causes a discontinuity in the ground plane.  creativity needed

Closed 2024-07-01.

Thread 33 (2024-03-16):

Keyboard PCB Improvements

Aeasala, 2024-03-16:
TBD

Aeasala, 2024-03-24:
update issue progress 3/24, see main comment

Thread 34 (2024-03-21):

Implement FPGA Display Driver

Aeasala, 2024-03-21:
this is going to be the big one.  probably an all-hands issue

Module is the Tang Nano 9K

Chip datasheet: https://www.mouser.com/datasheet/2/1033/DS117E-2820893.pdf

Current expected protocol is defined in [./serial-packet-protocol.yml](https://github.com/Apollo-Simulation-Peripheral-Lab/DSKY/blob/main/serial-packet-protocol.yml)

FPGA will need to store a DSKY state as provided through this serial protocol.  A method of rasterizing this state in a consistent, visually accurate & true-to-form manner shall be implemented.

Aeasala, 2024-07-01:
unfortunately, not moving forward with this.

cost savings are marginal vs. effort required & expandability.

Closed 2024-07-01.

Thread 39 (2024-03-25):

Future Power Management

Aeasala, 2024-03-25:
If deemed to be necessary, the 5V bus shall be conditionally isolated into {P5V_PWR} and {P5V_LOG} -- the former handling high-power sections, and the latter powering the microcontroller.

Net {P5V_PWR} shall be derived from either:

1. {P5V_LOG}, should {Vin_BARREL} be disconnected or <5V.

2. {Vin_BARREL}, bucked down to 5V, causing isolation between LOG and PWR.

Should more modules be created and integrated together, a "hub" of some sort shall be created to consolidate power distribution, and the USB bus of each module.

Should an EL variant ever be created, a HVAC inverter will be required.  The net will likely be isolated from USB power altogether, both in power and return.  A flyback converter would be used to create a sufficiently high DC voltage before inverting it to approx. 150V RMS @1kHz.  Harmonic distortion is not a concern for this application, unless found to cause electrical interference or harsh acoustic whining.

Aeasala, 2024-03-25:
[usb_aux_safe.zip](https://github.com/Apollo-Simulation-Peripheral-Lab/DSKY/files/14742312/usb_aux_safe.zip)

see ltspice sim for conditional bus switchover

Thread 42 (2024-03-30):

Cherry MX footprints should use PCB style, not plate style

Aeasala, 2024-03-30:
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

PCB switches have two extra pegs for NPTH, allowing more precise installation without concern of rotation/alignment

Aeasala, 2024-07-01:
direct merge in past.  completed

Closed 2024-07-01.

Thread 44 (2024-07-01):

Investigate feasibility of single board

Aeasala, 2024-07-01:
It's a given that mfg. cost of 2 boards is higher than one single board.

May be feasible to fit everything on a single board.

concerns are;

- I/O connections.  keyboard matrix is already littered everywhere, and we rely on a connector to bridge the signals over.  this would constrain everything to the traces of an already broadly (and necessarily) occupied 2-layer board.

Closed 2024-10-05.

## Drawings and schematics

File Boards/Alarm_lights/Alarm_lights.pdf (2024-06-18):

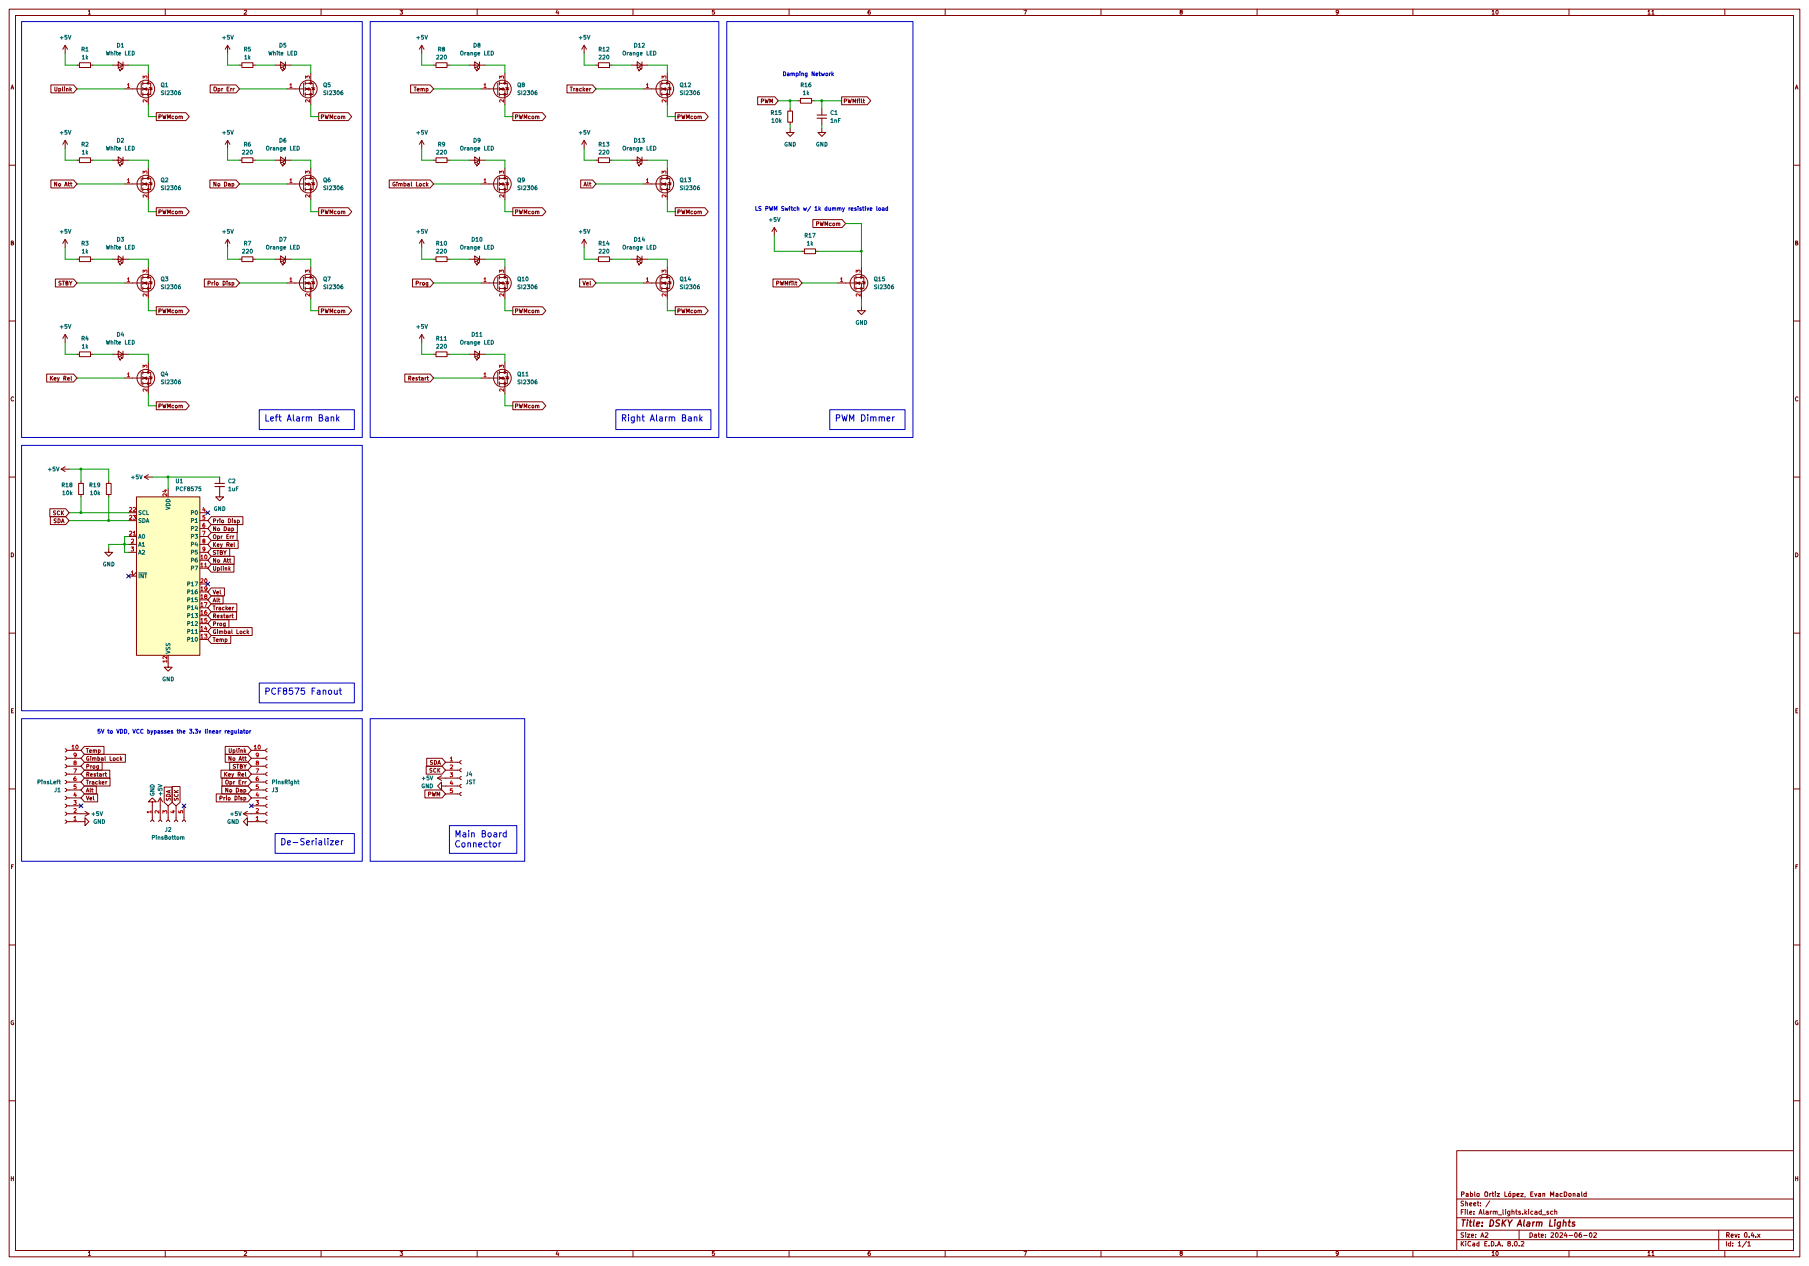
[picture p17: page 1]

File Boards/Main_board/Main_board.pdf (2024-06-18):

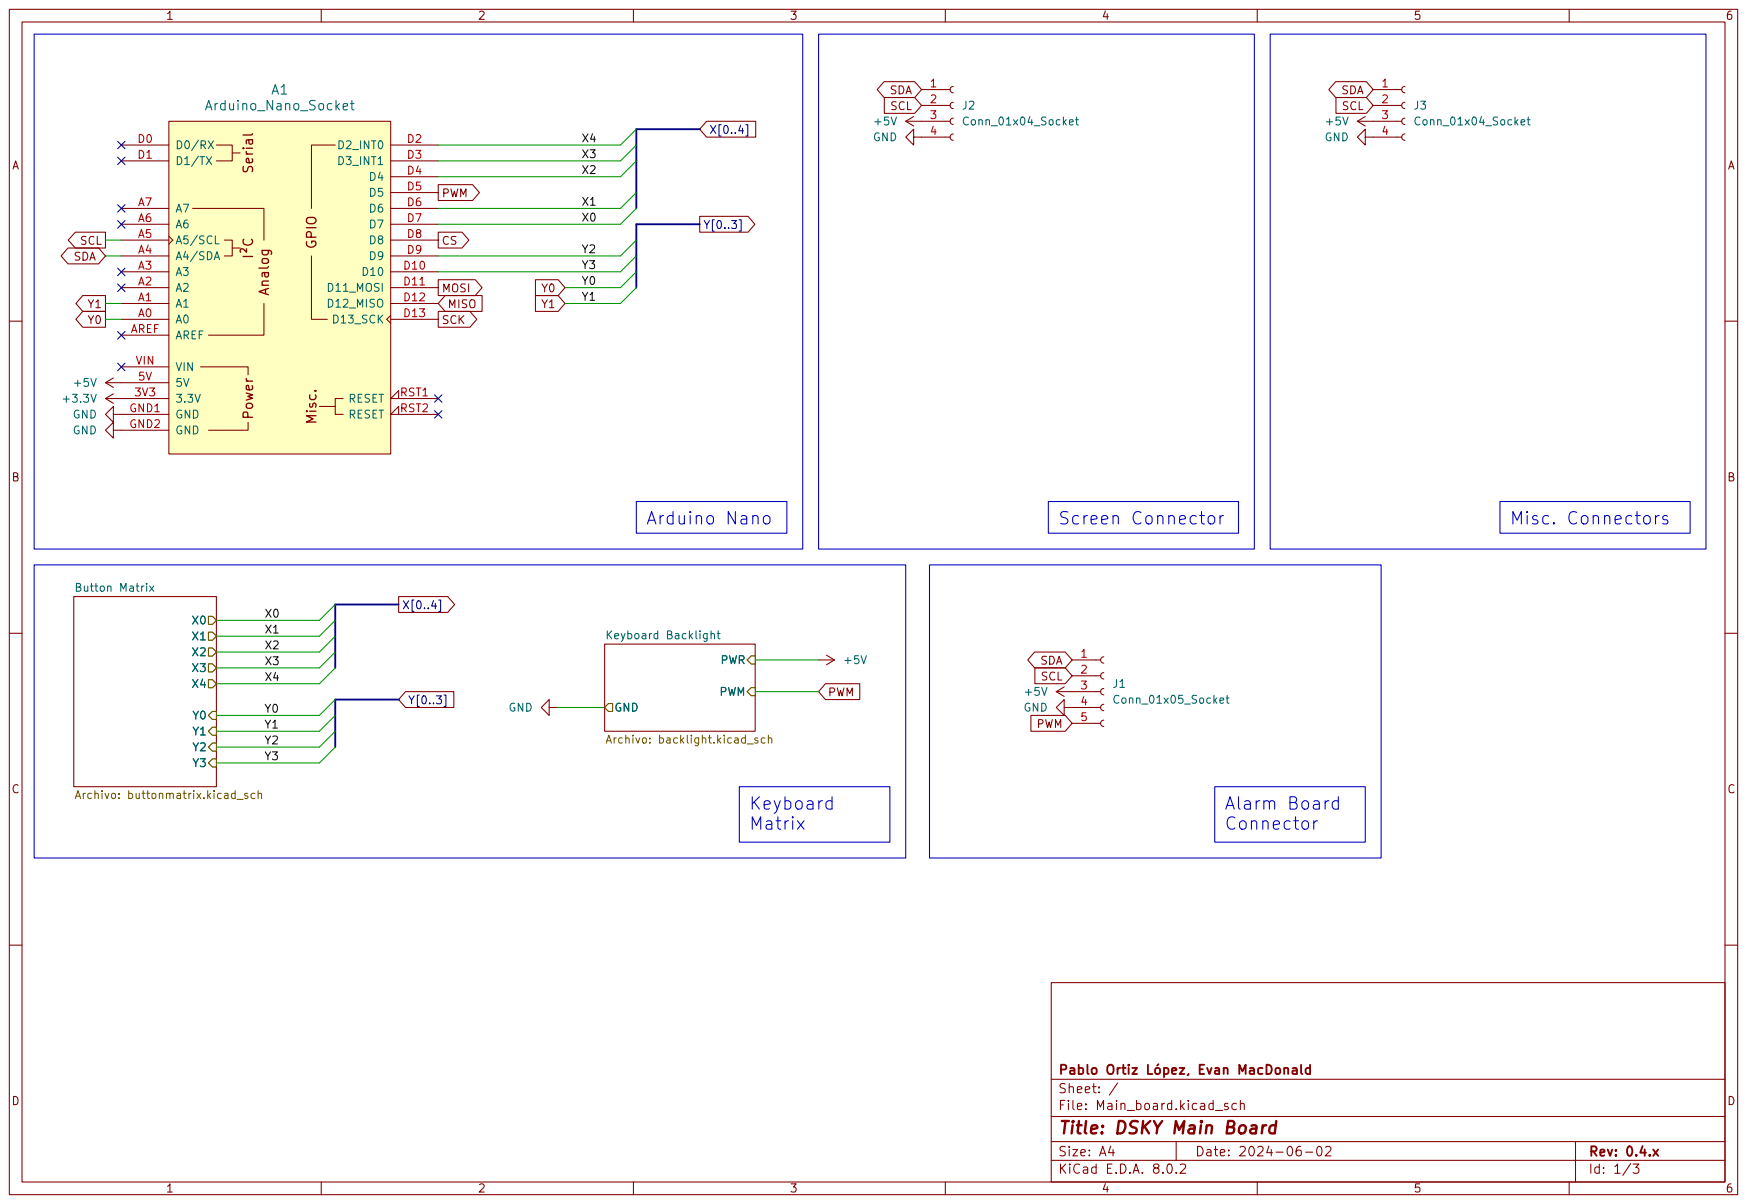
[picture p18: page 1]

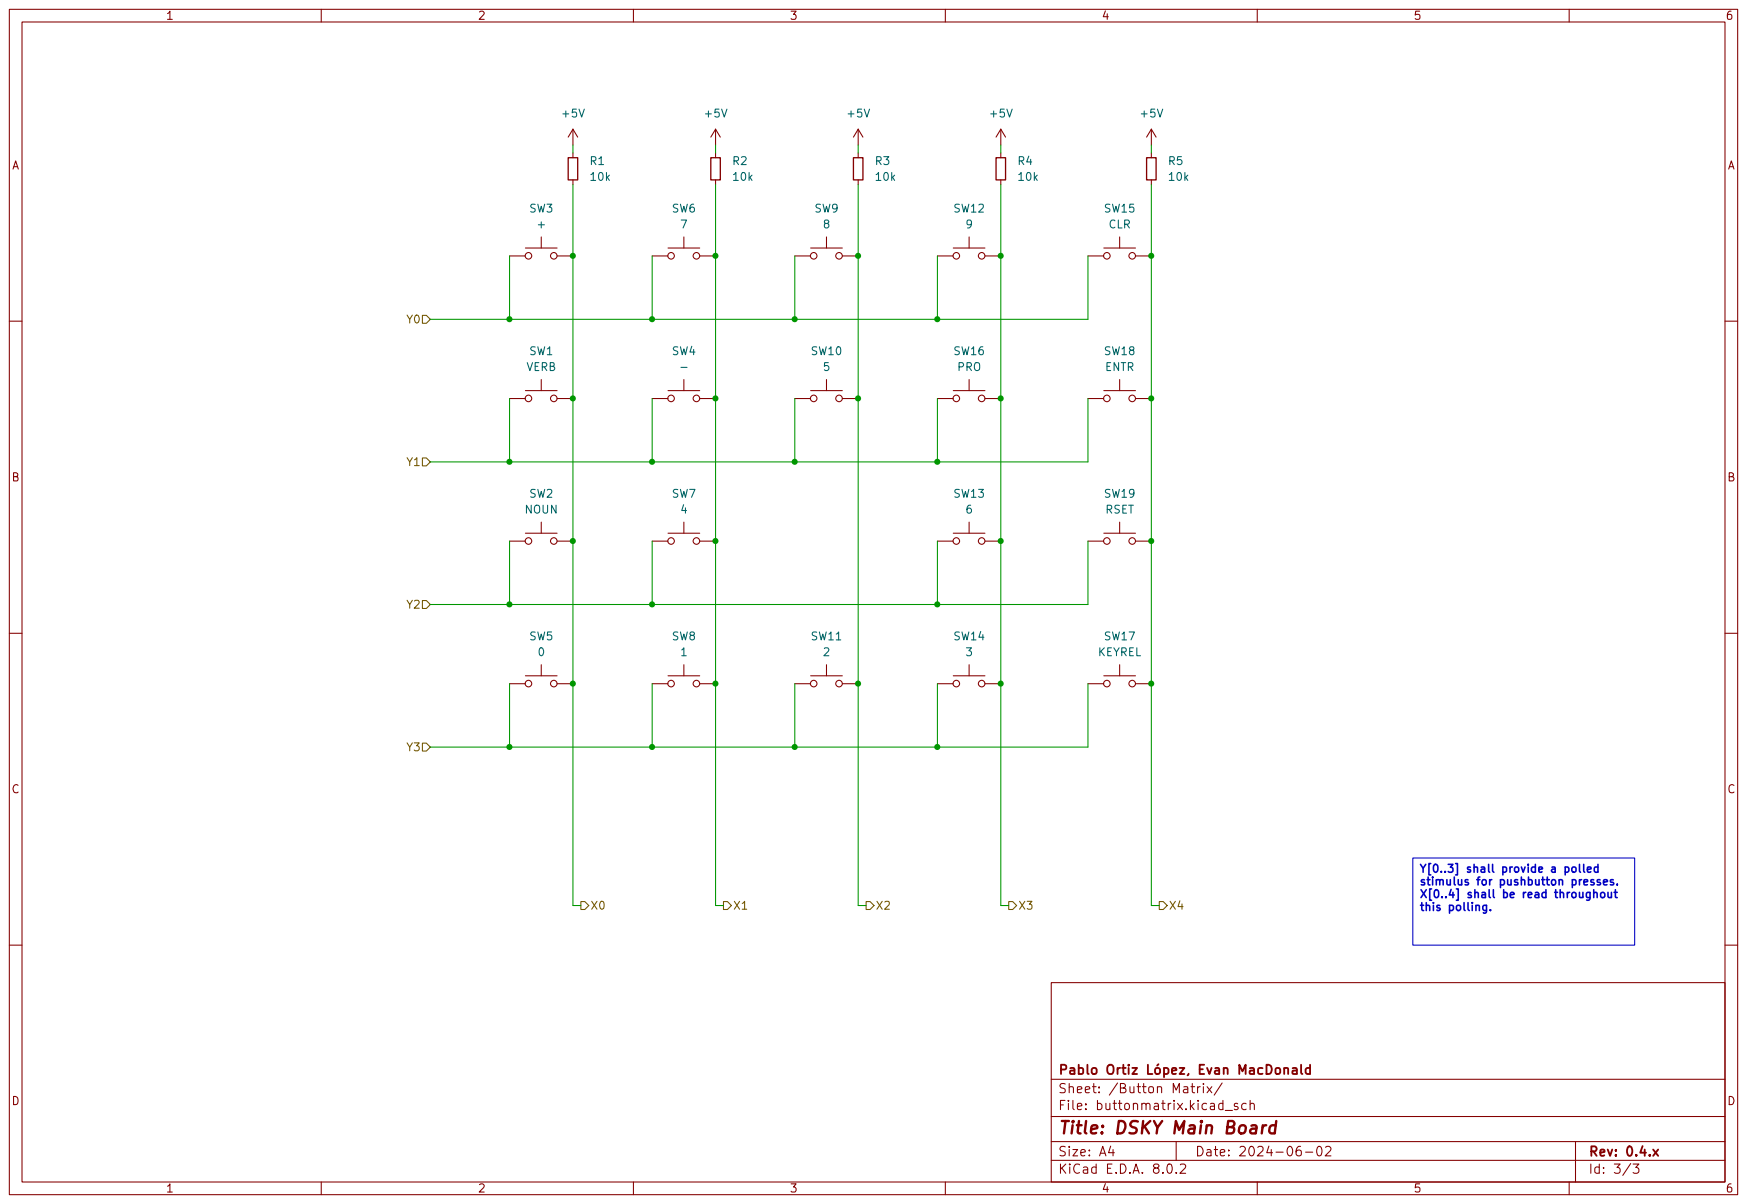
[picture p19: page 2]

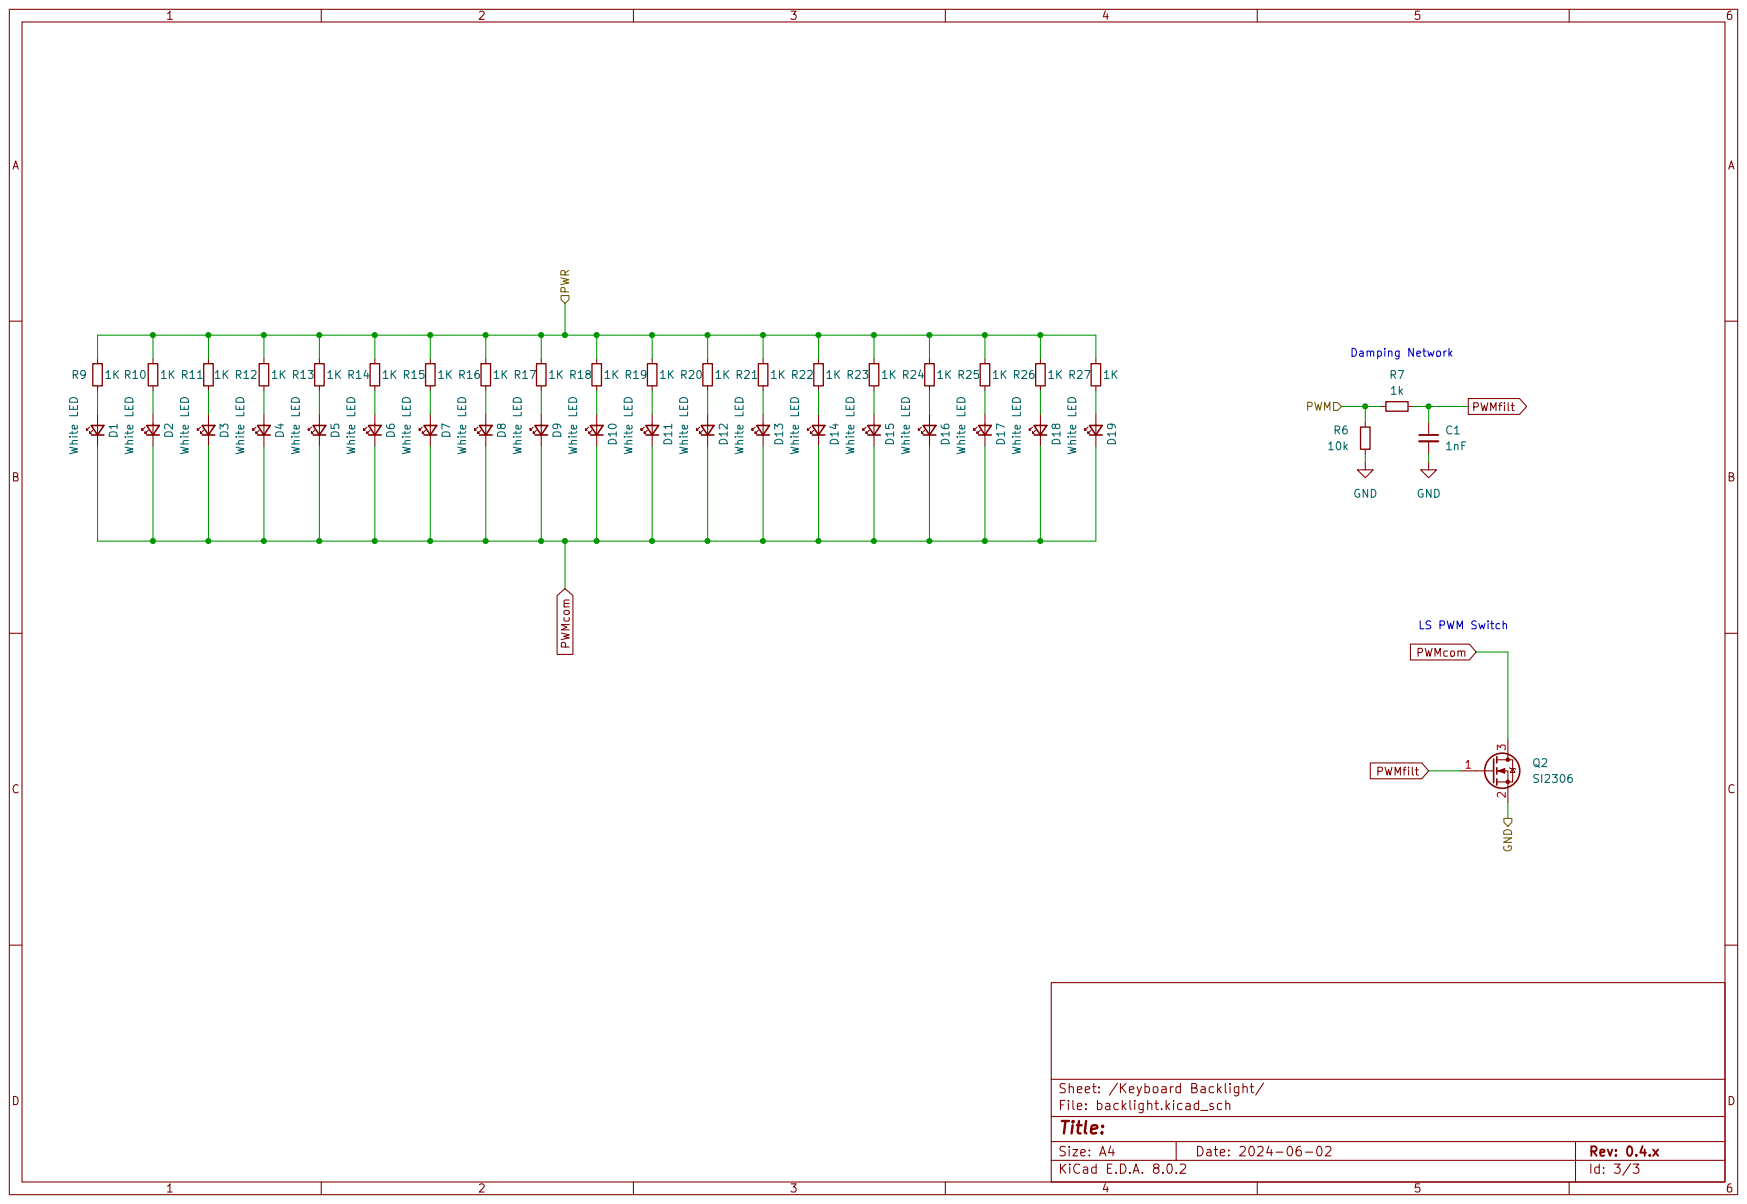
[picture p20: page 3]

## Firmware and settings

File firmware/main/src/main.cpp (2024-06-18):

#include <Arduino.h>
#include "alarms.h"
#include "keyboard.h"

using namespace std;

const uint8_t PACKET_SIZE = 15;
uint8_t dskyState[PACKET_SIZE];
uint8_t memoryLocation = 0;

// Initial debug state
bool serialByteReceived = false;
unsigned long lastRandomUpdate = 0;
unsigned long randomUpdateInterval = 1000; // Update every 1 second

void generateRandomDskyState() {
  for (int i = 0; i < PACKET_SIZE; i++) {
    if(i != 14) dskyState[i] = random(256); // Generate random byte values
    else dskyState[i] = 127; // Full brightness in christmas mode
  }
}

void setup() {
  Serial.begin(250000);
  initAlarms();
}

bool proPressed = false;
void loop() {
  // Generate random dskyState if no serial byte has ever been received
  if (!serialByteReceived && millis() - lastRandomUpdate >= randomUpdateInterval) {
    lastRandomUpdate = millis();
    generateRandomDskyState();
    updateAlarms(dskyState);
  }

  if(Serial.available() > 0){
    uint8_t receivedByte = Serial.read(); // Read the incoming byte
    serialByteReceived = true;

    if (receivedByte == 0xFF) { // Check if received byte is 0xFF
      memoryLocation = 0; // Reset the array index
    } else {
      dskyState[memoryLocation] = receivedByte; // Store the byte in the array
      memoryLocation = (memoryLocation + 1) % PACKET_SIZE; // Increment array index and wrap around if necessary
    }
  } 
  // Update alarms in every cycle so that bad IO chips can still work
  updateAlarms(dskyState);
  char pressedKey = getKey();
  if(pressedKey){
    Serial.println(pressedKey);
    if(pressedKey == 'P') proPressed = true;
  }
  if(getState() == RELEASED && proPressed){
    proPressed = false;
    Serial.println("O");
  }
}

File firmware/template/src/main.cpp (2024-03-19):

//////////////
/* Includes */
#include <Arduino.h>
#include "main.h"

////////////////////
/* Private Macros */
#if defined(BUILD_UNO)
#elif defined(BUILD_NANO)
#else
#endif

///////////////////
/* Private Types */

//////////////////
/* Private Data */

/////////////////////////////////
/* Private Function Prototypes */
void setup(void);
void loop(void);

/////////////////////////////////
/* Public Function Definitions */

//////////////////////////////////
/* Private Function Definitions */
void setup(void)
{
    Serial.begin(MONITOR_SPEED);
}

void loop(void)
{

}

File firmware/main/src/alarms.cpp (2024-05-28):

#include "alarms.h"
#include "PCF8575.h"
#include "Wire.h"

PCF8575 PCF(0x20);

void initAlarms(){
  pinMode(PWM_PIN, OUTPUT);
  analogWrite(PWM_PIN, 255);
  
  PCF.begin();
  
  Wire.begin();

  // initialize even the unused PCF pins to LOW state.
  for(uint8_t i = 0; i < 18; i++){
    PCF.write(i, LOW);
  }
}

/* Toggle a single {lamp} to a particular {state} */
void toggleAlarm(alarmLamp lamp, uint8_t state)
{
  PCF.write((uint8_t)lamp, state);
}

void updateAlarms(uint8_t *dskyState){
    // B6 Parsing
    uint8_t B6 = dskyState[6]; // B6 Value
    uint8_t UpLink = (B6 >> 4) & 0x01; // UpLink(A1) Value
    toggleAlarm(UPLINK_ACTY,UpLink);

    // B9 Parsing
    uint8_t B9 = dskyState[9]; // B9 Value
    uint8_t OprErr = (B9 >> 4) & 0x01; // OprErr(A5) Value
    uint8_t KeyRel = (B9 >> 5) & 0x01; // KeyRel(A4) Value
    uint8_t Stby = (B9 >> 6) & 0x01; // KeyRel(A3) Value
    uint8_t NoAtt = (B9 >> 7) & 0x01; // NoAtt(A2) Value
    toggleAlarm(OPR_ERR,OprErr);
    toggleAlarm(KEY_REL,KeyRel);
    toggleAlarm(STBY,Stby);
    toggleAlarm(NO_ATT,NoAtt);

    // B12 Parsing
    uint8_t B12 = dskyState[12]; // B12 Value
    uint8_t Tracker = (B12 >> 1) & 0x01; // Tracker(A12) Value
    uint8_t Restart = (B12 >> 2) & 0x01; // Restart(A11) Value
    uint8_t Prog = (B12 >> 3) & 0x01; // Prog(A10) Value
    uint8_t GimbalLock = (B12 >> 4) & 0x01; // GimbalLock(A9) Value
    uint8_t Temp = (B12 >> 5) & 0x01; // Temp(A8) Value
    uint8_t PrioDisp = (B12 >> 6) & 0x01; // PrioDisp(A7) Value
    uint8_t NoDap = (B12 >> 7) & 0x01; // NoDap(A6) Value
    toggleAlarm(TRACKER,Tracker);
    toggleAlarm(RESTART,Restart);
    toggleAlarm(PROG,Prog);
    toggleAlarm(GIMBAL_LOCK,GimbalLock);
    toggleAlarm(TEMP,Temp);
    toggleAlarm(PRIO_DISP,PrioDisp);
    toggleAlarm(NO_DAP,NoDap);

    // B13 Parsing
    uint8_t B13 = dskyState[13]; // B13 Value
    uint8_t Vel = (B13 >> 6) & 0x01; // Vel(A14) Value
    uint8_t Alt = (B13 >> 7) & 0x01; // Vel(A13) Value
    toggleAlarm(VEL,Vel);
    toggleAlarm(ALT,Alt);

    uint8_t brightness = (dskyState[14] << 1) | 1;
    analogWrite(PWM_PIN, brightness);
}

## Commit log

2024-02-11 First revision of Alarm Lights PCB
    [Alarm_lights.kicad_pcb, Alarm_lights.kicad_sch]
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2024-02-13 Move KiCad project to correct location
    [Alarm_lights.kicad_pcb, Alarm_lights.kicad_sch]
2024-02-14 Update 3D Models and readme
    [Alarm BOTTOM.3mf, Alarm Holder.3mf, Alarm Splitter.3mf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]
2024-02-14 Change structure & update OLED TOP
    [Alarm BOTTOM.3mf, Alarm Holder.3mf, Alarm Splitter.3mf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]
2024-02-16 Fix OLED top height
    [OLED TOP.3mf]
2024-02-18 Position elements in board
    [Alarm_lights.kicad_pcb, Alarm_lights.kicad_sch]
2024-02-18 First attempt at routing PCB & insert into f3d
    [Alarm_lights.dsn, Alarm_lights.kicad_pcb, Alarm_lights.kicad_sch]
2024-02-22 Update Alarm lights pcb to use BJT's, a different IO Expander, and fit correctly into f3d assembly
    [Alarm_lights.kicad_pcb, Alarm_lights.kicad_sch]
2024-02-24 Main board keyboard matrix schematic
    [Main_board.kicad_pcb, Main_board.kicad_sch]
2024-02-24 Complete RHS of board
    [Alarm_lights.kicad_pcb]
2024-02-24 Update diode reference & footprint in schematic file
    [Main_board.kicad_sch]
2024-02-24 Checkpoint for addition of UNO
    [Main_board.kicad_pcb, Main_board.kicad_sch, uno.kicad_sch]
2024-02-24 Correct ground port on uno sheet to not use global power symbol
    [uno.kicad_sch]
2024-02-24 Correct P5V I/O direction, should be output while USB powered.
    [Main_board.kicad_sch, uno.kicad_sch]
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2024-02-25 Move button matrix to separate sheet in hierarchy. General tidying, give values to B2B Uno connectors.
    [Main_board.kicad_pcb, Main_board.kicad_sch, buttonmatrix.kicad_sch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]
2024-02-25 add schematic output. fix ground reference in I/O pin
    [uno.kicad_sch]
2024-02-25 Positioned DSKY pushbuttons according to mech. drawing and reference .STEP file.
    [Main_board.kicad_pcb]
2024-02-25 Major checkpoint on button matrix wiring.
    [Main_board.kicad_pcb, Main_board.kicad_sch]
2024-02-25 Fix clearances for screws on bottom parts of enclosures
    [Alarm BOTTOM.3mf, OLED BOTTOM.3mf]
2024-02-25 Fix tolerances of alarm and oled bottom parts
    [Alarm BOTTOM.3mf, OLED BOTTOM.3mf]
2024-02-25 Change to FET-based switching. Add PWM dimming.
    [Alarm_lights.kicad_pcb, Alarm_lights.kicad_sch]
2024-02-25 Fix clearance on top cover for the iPhone design
    [TOP Cover.3mf]
2024-02-26 Fix coordinate system wrt origin, clean up some asymmetries
    [Alarm_lights.kicad_pcb, Alarm_lights.kicad_sch]
2024-02-26 Main board order, prototyping checkpoint.
    [Main_board.kicad_pcb, Main_board.kicad_sch]
2024-02-26 Checkpoint for prototyping board order
    [Alarm_lights.kicad_pcb]
2024-02-26 Add Top cover variants
    [TOP Cover.3mf, TOP Cover_IPhone.3mf, TOP Cover_LCD.3mf]
2024-02-26 Match enclosure heights with oled
    [Alarm BOTTOM.3mf, Alarm TOP.3mf]
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2024-02-29 Fix positioning of IO Board pins & matched grid to MIT drawings. Routing lost
    [Alarm_lights.kicad_pcb]
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2024-03-01 Precision component alignment to grid, center LEDs.
    [Alarm_lights.kicad_pcb]
2024-03-01 Add c9opper edge clearance
    [Alarm_lights.kicad_pcb]
2024-03-01 Partial route on top layer
    [Alarm_lights.kicad_pcb]
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2024-03-01 Move Arduino, JST to flipside.
    [Main_board.kicad_pcb, Main_board.kicad_sch]
2024-03-01 Fix small DRC issue, add title, generate gerbers
    [Alarm_lights-B_Cu.gbl, Alarm_lights-B_Mask.gbs, Alarm_lights-B_Paste.gbp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]
2024-03-01 Fix typo
    [Alarm_lights.kicad_pcb]
2024-03-01 Minor update to date, revision, authors, and Schematic output.
    [Alarm_lights.kicad_sch]
2024-03-01 Update layout so that the board fits in the DSKY
    [Main_board-B_Cu.gbl, Main_board-B_Mask.gbs, Main_board-B_Paste.gbp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]
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2024-03-02 Change to Arduino Nano, fit board into DSKY
    [Main_board-B_Cu.gbl, Main_board-B_Mask.gbs, Main_board-B_Paste.gbp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]
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2024-03-02 Correct missing ground connection on uC. Upcoming board re-routing
    [Main_board.kicad_sch, buttonmatrix.kicad_sch]
2024-03-02 Update gerbers, fix DRC, use custom library for cherry switches
    [Main_board-B_Cu.gbl, Main_board-B_Mask.gbs, Main_board-B_Paste.gbp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]
2024-03-02 Update alarms board gerber files
    [Alarm_lights-B_Cu.gbl, Alarm_lights-B_Mask.gbs, Alarm_lights-B_Paste.gbp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]
2024-03-02 Add silkscreen credits and update gerbers
    [Main_board-B_Cu.gbl, Main_board-B_Mask.gbs, Main_board-B_Paste.gbp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]
2024-03-03 Correct revisions to match upcoming tagged release
    [Alarm_lights.kicad_sch, Main_board.kicad_sch, buttonmatrix.kicad_sch]
2024-03-05 Switch to pullups on IO from prototype findings
    [Alarm_lights.kicad_pcb, Alarm_lights.kicad_sch]
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2024-03-05 Re-structure 3d folders and update readme
    [OLED BOTTOM.3mf, OLED TOP.3mf, TOP Cover_IPhone.3mf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]
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2024-03-07 PWM FET damping, tau of ~1us/LPF of 150khz. Eliminates coupling from orange LED @ low duty
    [Alarm_lights.kicad_pcb, Alarm_lights.kicad_sch]
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2024-03-07 Tidy up and complete stitching. Regen gerbers.
    [Main_board-B_Cu.gbl, Main_board-B_Mask.gbs, Main_board-B_Paste.gbp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]
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2024-03-07 Reannotate, regen gerbers. Add silkscreen markings for intended lamp text.
    [Alarm_lights-B_Cu.gbl, Alarm_lights-B_Mask.gbs, Alarm_lights-B_Paste.gbp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]
2024-03-07 45deg spokes where appropriate
    [Alarm_lights-B_Cu.gbl, Alarm_lights-B_Mask.gbs, Alarm_lights-B_Paste.gbp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]
2024-03-07 Update mesh files to reflect latest changes in the assembly
    [Alarm BOTTOM.3mf, Alarm Holder.3mf, Alarm Splitter.3mf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]
2024-03-07 Alarm board: change revision scheme, update on silkscreen. Regen gerbers.
    [Alarm_lights-B_Cu.gbl, Alarm_lights-B_Mask.gbs, Alarm_lights-B_Paste.gbp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]
2024-03-07 Main board: change revision scheme, update on silkscreen. Regen gerbers.
    [Main_board-B_Cu.gbl, Main_board-B_Mask.gbs, Main_board-B_Paste.gbp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]
2024-03-07 Attach known-good P/Ns to components, generate BOM (finally)
    [Alarm_lights.csv, Alarm_lights.kicad_pcb, Alarm_lights.kicad_sch]
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2024-03-07 Add main board bom
    [Main_board.csv, Main_board.kicad_sch, buttonmatrix.kicad_sch]
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2024-03-08 [3d] Improve clearances in alarm holder & gasket top
    [Alarm Holder 3x7mm.3mf, Alarm Holder 3x9mm.3mf, Alarm Holder.3mf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]
2024-03-09 #19 Improve countersunk screw holes on gasket top
    [Gasket Top.3mf]
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2024-03-10 Issue #16: Add modified ILI9488 display driver for future work. Includes sample .ino project.
2024-03-11 Avoid serial output from interrupting serial re-connect prompt
2024-03-13 Correct IO expander indices
    [main.cpp]
2024-03-13 Correct IO expander pinout. VDD was not labeled correctly.
    [Alarm_lights.kicad_pcb, Alarm_lights.kicad_sch]
2024-03-13 Update boards to reflect new version.
    [Alarm_lights-B_Cu.gbl, Alarm_lights-B_Mask.gbs, Alarm_lights-B_Paste.gbp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]
2024-03-13 Update main boards, as well.
    [Main_board-B_Cu.gbl, Main_board-B_Mask.gbs, Main_board-B_Paste.gbp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]
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2024-03-13 Change dummy load placement in schematic to make its function more apparent.
    [Alarm_lights-B_Cu.gbl, Alarm_lights-B_Mask.gbs, Alarm_lights-B_Paste.gbp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]
2024-03-14 Add missing no-connect, tidy up some net names. Resolve some discontinuities in PWMcom
    [Alarm_lights-B_Cu.gbl, Alarm_lights-B_Mask.gbs, Alarm_lights-B_Paste.gbp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]
2024-03-14 Correct some directions on the main board schematic. Replot schematics for both boards, refresh gerbers and BOM.
    [Main_board-B_Cu.gbl, Main_board-B_Mask.gbs, Main_board-B_Paste.gbp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]
2024-03-14 Update reentry.ts
    Note: Code is untested hence the new branch
    - Added Error catch for JSON parsing
    - Replaced switch case with a KeyMap (Using NASSP Chords)
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2024-03-14 Hotfix: some silkscreen elements missing due to footprint parameter type, corrected.
    [Main_board-B_Cu.gbl, Main_board-B_Mask.gbs, Main_board-B_Paste.gbp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]
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2024-03-16 Change PWM filter to use one less unique component.
    [Alarm_lights.csv, Alarm_lights.kicad_pcb, Alarm_lights.kicad_sch]
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2024-03-30 #42 : Footprint swap, correct minor overlaps
    [Main_board.kicad_pcb, buttonmatrix.kicad_sch]
2024-06-03 Make keys better printable
    [+.3mf, -.3mf, 0.3mf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]
2024-06-05 Add key manufacturing tool & reduce alarms cover height
    [Alarm Housing Bottom.3mf, Alarm Splitter.3mf, Key Manufacturing Tool.3mf]
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2024-06-07 Adjust keyboard plate clearance
    [Keyboard Plate.3mf]
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2024-06-11 Fix alarm cover thickness
    [Alarm Housing Bottom.3mf, Alarm Splitter.3mf]
2024-06-14 Reinforced Keys & Split Mount in half
    [+.3mf, +.stl, -.3mf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]
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2024-06-16 firmware - Fix self-test mode
    [main.cpp]
2024-06-16 firmware - Fix self-test mode while keeping support for bad io chips
    [main.cpp]
2024-06-18 Lower keyboard and fix self test
    [Keyboard Holder.3mf]
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2024-06-23 Tolerance adjustments
    [Cover (HDMI).stl, Cover+Frame (HDMI).stl, Keyboard Plate.stl]
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2024-06-24 Modify Mainboard to enable support for PCB type switches
    [JLC_Both.xlsx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]
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2024-06-30 Tie numerics to led brightness for nassp while integrals is missing
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2026-06-13 Add over-the-air update system
    Devices update themselves from the DSKY menu (SETTINGS > UPDATE) by pulling
    prebuilt release packages from GitHub, with atomic install and automatic
    rollback so a bad update can never brick a device.
    - updater.ts: check GitHub releases, download + checksum-verify, install into
    versioned release dirs with an atomic symlink switch, carry over device
    config, and a verify/rollback flag for crash-looping releases
    - UPDATE menu entry in SETTINGS (with NEW badge), update status screen, and
    installed version shown in ABOUT
    - orangepi.sh: launch from the active release symlink, fall back to the
    untouched factory install, and roll back a crash-looping fresh upda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
2026-06-13 Polish menu icons with lucide-react
    Replace the plain unicode-glyph icons (settings, apps, commands, reboot,
    calculator, etc.) with consistent lucide line icons, and give UPDATE a proper
    cloud-download SVG. The hand-drawn themed icons (rocket, NASSP gears, reentry,
    KSP, yaAGC, wifi) are kept for personality.
2026-06-13 Make release workflow deterministic and self-verifying
    The previous publish step could report success without actually creating a
    visible release. Now it deletes any prior release for the tag, creates it
    explicitly as the latest published release, and asserts both assets are
    attached (failing loudly otherwise).
2026-06-13 add snake game
    Board is 14×24 to match the DSKY screen aspect ratio so cells render
    roughly square. Controls: 4/6/8/2 directions, ENTR start/pause,
    RSET back to selector. Direction input is validated against
    pendingDirection (not the applied direction) so a quick two-tap
    can't collapse into a 180° reversal between ticks.
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2026-06-13 add minesweeper game
    9×9 board with 10 mines (classic beginner difficulty). Controls:
    4/6/8/2 cursor, ENTR reveal, + flag, RSET back to selector. First
    reveal is guaranteed safe — mines are seeded after the player's
    first click, avoiding the chosen cell. Floods empty regions on
    reveal and tracks best win time per session.
    Also tightens the games selector spacing so five entries fit
    comfortably without scroll.
2026-06-13 consolidate RSET handling in the games hub
    Factor the back-to-selector flow out of each per-game branch into a
    single `resetActiveGameToSelector` helper switched on activeGame,
    and hoist the `if (key === 'r')` check above the per-game branches.
    Same behavior, one path instead of five, and new games can ignore
    the concern entirely.
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
